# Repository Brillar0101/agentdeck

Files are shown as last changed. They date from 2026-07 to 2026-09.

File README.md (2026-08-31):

<div align="center">

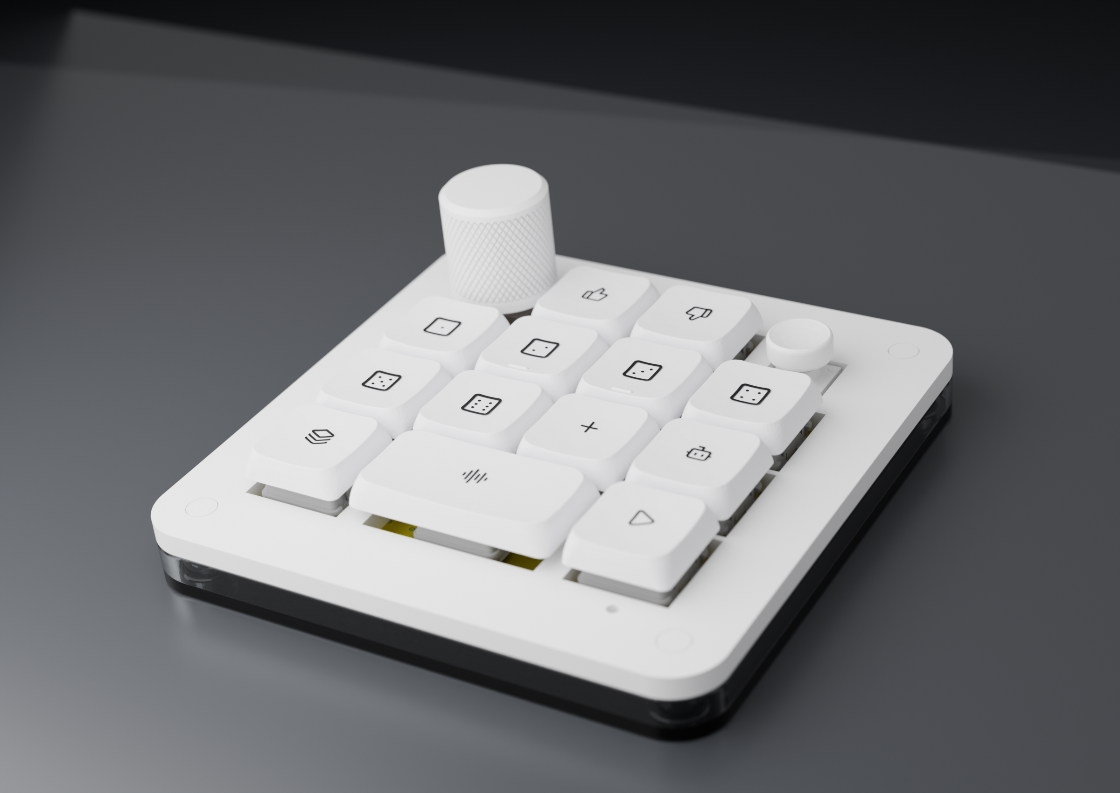
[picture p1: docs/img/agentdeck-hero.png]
AgentDeck v1


# AgentDeck

**AgentDeck is an open-source desk macropad for supervising AI coding agents.**

</div>

_AgentDeck is optimized for people running several coding agents at once who
want glanceable status and one-hand control. It is a desk device, not a
portable one: USB-C only, no battery, no radio._

- [Design notes](v1/DESIGN.md)
- [Changelog](CHANGELOG.md)
- [Licensing](LICENSING.md)

Six agent keys light up with each agent's live state (idle, thinking, working,
blocked, done). Press one to focus that session. The command keys accept or
reject work, the dial scrubs and confirms, and the joystick navigates. A host
bridge maps Claude Code hooks to the key colours, so the board answers "which
of my sessions needs me?" without alt-tabbing.

> **This is a Codex Micro-inspired project.** The concept follows OpenAI and
> Work Louder's Codex Micro, and the control layout deliberately echoes it. It
> is an independent build, not affiliated with, endorsed by, or produced with
> OpenAI, Work Louder, or Anthropic. The board, firmware and enclosure are
> original work; no Codex Micro files were used. Some material in this
> repository (vendor footprints, datasheets, reference photographs, third-party
> cap and knob models) is not ours to license. See [LICENSING.md](LICENSING.md).

## Renders

| | |
|---|---|
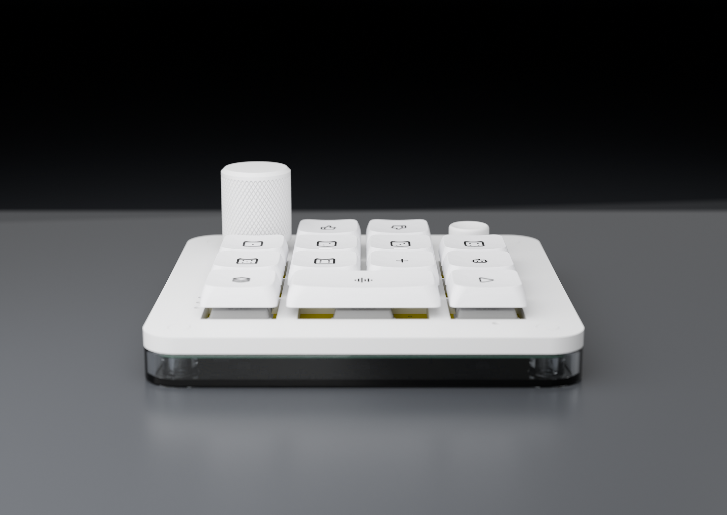
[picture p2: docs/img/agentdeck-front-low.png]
front
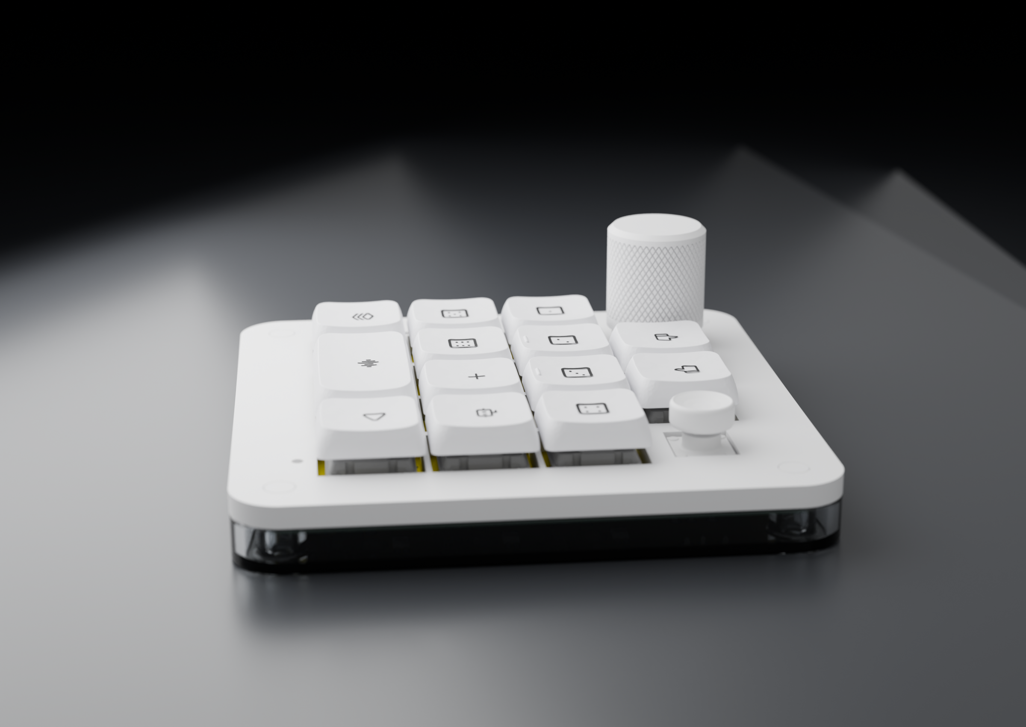
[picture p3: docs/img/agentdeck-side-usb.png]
side
|  |  |
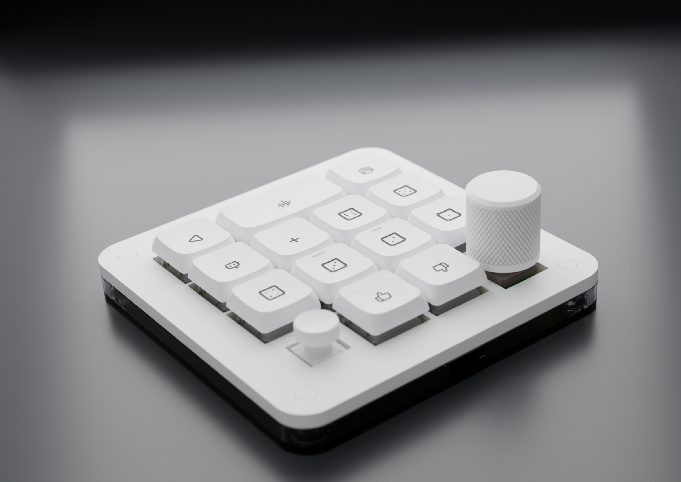
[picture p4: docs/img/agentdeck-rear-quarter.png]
rear
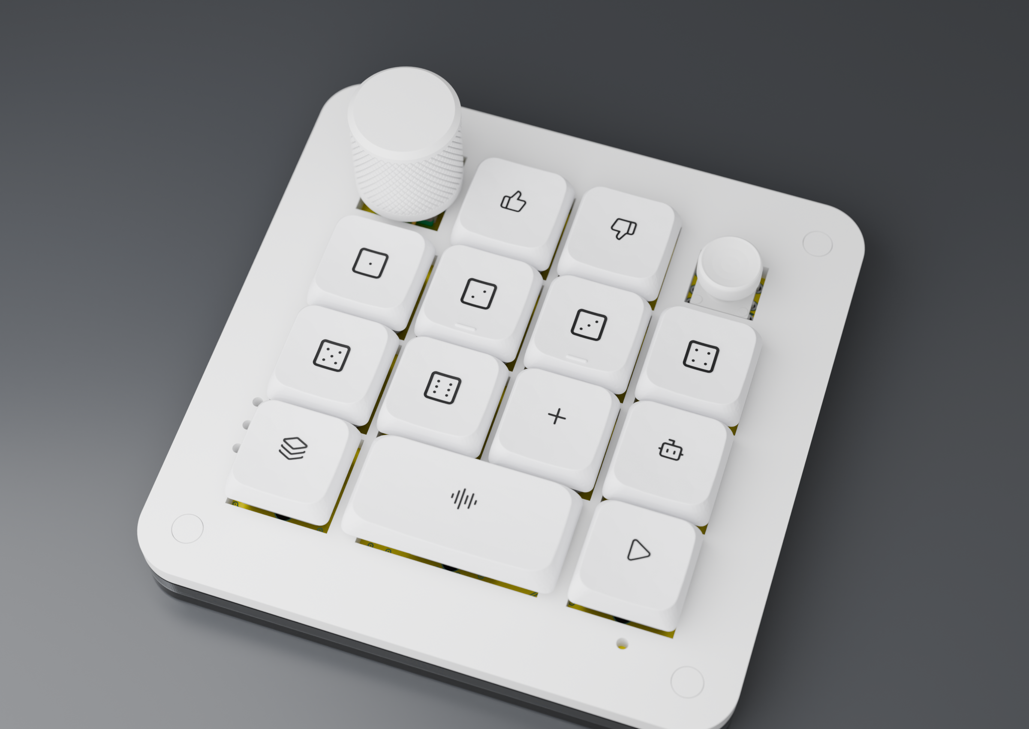
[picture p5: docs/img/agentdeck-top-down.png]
top
|  |  |

## Changelog

Hardware revisions are tracked in the [changelog](CHANGELOG.md). Because the
board is text-based KiCad, every fabricated revision maps to a tagged commit,
and a physical board can be traced back to the exact design it was made from.

## Versions

| Version | What it is | Where |
|---|---|---|
| **V1** (this release) | 95 x 95 mm 4-layer RP2040 board, 13 keys, JLCPCB PCBA | `v1/hardware/` |

What comes next (v1.0 bring-up, the v1.1 depth release, and what is
deliberately parked) is in the [roadmap](docs/ROADMAP.md).

## Status

| Part | State |
|---|---|
| Schematic + PCB | Complete. 4 layers, fully routed, 0 DRC errors, 0 ERC errors |
| Firmware | Written (CircuitPython, plus an Arduino/C++ port), untested on hardware |
| Host bridge | Written. Maps Claude Code hooks to agent-key colours |
| Enclosure | Modelled and fit-checked in Blender, STLs exported, not yet printed |
| Fab package | Gerbers, BOM and CPL generated for JLCPCB |

Nothing has been manufactured yet, so none of it is hardware-verified.

## Packages

The repository is organized by discipline. Each directory is self-contained
and has its own README where the workflow needs explaining.

| Directory | Contents |
|---|---|
| `v1/hardware/` | KiCad 10 project: `AgentDeck.kicad_pcb`, `AgentDeck.kicad_sch`, footprint / symbol / 3D libraries |
| `v1/enclosure/` | Blender assembly (`AgentDeck-v2-assembled.blend`), the parametric case generator (`src/generate_case.py`), printable STLs, keycap icon art |
| `v1/firmware/` | CircuitPython firmware (`boot.py`, `code.py`) and the Arduino port |
| `v1/host/` | `agentdeck_bridge.py`, the Claude Code hook bridge |
| `v1/fab/` | Gerbers, drill files, BOM and CPL for JLCPCB |
| `docs/` | design notes, datasheets, reference material, renders in `docs/img/` |
| `LICENSES/` | full licence texts |

## Hardware

The board is a 95 x 95 mm 4-layer PCB, drawn in KiCad 10.

- 13 Kailh Choc hot-swap keys on an 18.7 x 19.3 mm grid, each with a
  reverse-mount SK6812MINI-E RGB LED shining up through the cap
- EC11 rotary encoder (top left) and Alps SKQUCAA010 5-way joystick (top right)
- RP2040 with W25Q128 16 MB flash, USB-C, BOOT button, SWD pads
- Everything is wired directly to GPIO. There is no key matrix, so there is
  no ghosting to debounce around
- All SMD parts sit on the back of the board and hang down into the case
  tray; only the switches, encoder and joystick face up

Keycaps carry simple engraved-style icons (dice for the six agent keys,
thumbs up and down for accept and reject) rendered from
[Lucide](https://lucide.dev) glyphs. The encoder and joystick caps are white.

## Enclosure

Two printed parts plus four printed cover caps. The PCB drops into the bottom
tray component-side down, the lid closes over it, and four screws clamp the
stack into brass inserts.

| Feature | Spec |
|---|---|
| Screws | M2.5 x 8 mm button head (ISO 7380), head 4.7 x 1.3 mm |
| Lid | 5.2 mm counterbore, 2.5 mm deep, over a 2.9 mm shaft hole |
| Inserts | M2.5 brass heat-set, 4.0 mm OD x 5.0 mm, melted into a 3.6 mm boss bore |
| Cover caps | printed 5.0 x 1.2 mm plugs that hide the screw heads |
| Fit | 0.4 mm pocket clearance around the board (a deliberately loose fit) |
| USB | side port through the tray wall, sized for the plug plus a slim overmould |
| Walls | 2.6 mm, with a 0.6 mm bevel on exposed edges |

Print `v1/enclosure/case-bottom.stl`, `v1/enclosure/case-top-lid.stl`, and four of
`v1/enclosure/case-cover-plug.stl`. The case is generated, not sculpted: edit the
parameters in `v1/enclosure/src/generate_case.py` and re-run it to get new STLs.

## Firmware

Copy `v1/firmware/boot.py` and `code.py` onto a CIRCUITPY drive running
CircuitPython 9.x, with `adafruit_hid` and `neopixel` in `lib/`. An Arduino
port with identical behaviour lives in `v1/firmware/arduino/` if you prefer a
compiled build.

The command keys send Ctrl+Alt chords, the dial sets reasoning effort, and the
joystick navigates. `v1/firmware/README.md` has the full control table, colour
legend, pin map, and the three constants to confirm on first hardware.

## Development

- **Board edits**: open `v1/hardware/AgentDeck.kicad_pcb` in KiCad 10. After
  copper changes, refill zones before running DRC, then regenerate `v1/fab/`
  with `kicad-cli`.
- **Case edits**: run `v1/enclosure/src/generate_case.py` in Blender to rebuild
  the STLs from parameters.
- **Renders**: the assembly lives in `v1/enclosure/AgentDeck-v2-assembled.blend`;
  reference renders are committed under `docs/img/`.
- Derived files (board 3D exports, `.dsn`/`.ses` routing intermediates,
  autorouter logs) are gitignored and regenerate from the board.

## Licence

Multi-licensed, as is normal for open hardware. See [LICENSING.md](LICENSING.md).

| What | Licence |
|---|---|
| Software (`v1/firmware/`, `v1/host/`) | [MIT](LICENSES/MIT.txt) |
| Hardware (board, enclosure, fab files) | [CERN-OHL-S v2](LICENSES/CERN-OHL-S-v2.txt) |
| Documentation | [CC-BY-4.0](LICENSES/CC-BY-4.0.txt) |

Vendor footprints, datasheets and reference images keep their original terms.
Keycap icons are from [Lucide](https://lucide.dev) (ISC).

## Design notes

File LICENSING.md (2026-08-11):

# Licensing

AgentDeck is an open-hardware project, so different parts carry different
licences. This is the usual split for open hardware — one licence cannot sensibly
cover source code, a PCB design, and written documentation at once.

| What | Covers | Licence |
|---|---|---|
| **Software** | `firmware/`, `host/`, `*.py` | [MIT](LICENSES/MIT.txt) |
| **Hardware** | `*.kicad_pcb`, `*.kicad_sch`, `*.kicad_sym`, `*.pretty/`, `fab/`, `enclosure/*.stl`, `enclosure/*.blend`, enclosure models | [CERN-OHL-S v2](LICENSES/CERN-OHL-S-v2.txt) |
| **Documentation** | `README.md`, `DESIGN.md`, `PLAN.md`, `*/README.md`, images | [CC-BY-4.0](LICENSES/CC-BY-4.0.txt) |

SPDX identifiers: `MIT`, `CERN-OHL-S-2.0`, `CC-BY-4.0`.

The root `LICENSE` file is the MIT text so GitHub reports a licence; it applies
to the software only. Hardware and documentation are governed by the table above.

## What each one means

**MIT** (software) — do anything, including commercially and in closed products;
just keep the copyright notice. No warranty.

**CERN-OHL-S v2** (hardware) — *strongly reciprocal*. You may study, modify,
manufacture and sell the board and enclosure, but if you distribute a modified
design, or a product made from it, you must release your design sources under
CERN-OHL-S as well. This keeps derivatives open.

**CC-BY-4.0** (documentation) — reuse and adapt the writing and figures, with
attribution.

### If you would rather not have the share-alike condition

Swap the hardware licence to [CERN-OHL-P v2](https://ohwr.org/project/cernohl)
(permissive — no obligation to publish your modifications). That is a one-file
change plus an edit to the table above. CERN-OHL-S was chosen as the default
because it keeps improvements to the board flowing back to the community.

## Third-party material

Some content in this repository is **not** covered by the licences above and
remains under its original terms:

- `JLC.3dshapes/`, `JLC.pretty/` — component footprints and 3D models from LCSC /
  JLCPCB and their manufacturers
- `docs/datasheets/`, `docs/reference/*.pdf` — vendor documentation (Raspberry Pi,
  Alps and others), redistributed for reference only
- `docs/reference/*.webp`, `docs/reference/*.png` — **product photographs of
  OpenAI / Work Louder's Codex Micro.** These are not ours, are used only as
  design reference, and are **not** licensed for redistribution. Remove them
  before making this repository public.
- `docs/reference/pi-codex-micro/` — a clone of a third-party project
  (github.com/jal-co/pi-codex-micro) under its own licence; excluded from git
- `enclosure/keycaps/`, `enclosure/encoder/` — keycap and knob models sourced from their
  respective authors; check the original terms before redistributing

## Inspiration and independence

AgentDeck is an **independent, Codex Micro-inspired project**. The idea of a
macropad for supervising coding agents — agent keys that show live state, an
accept/reject pair, a reasoning-effort dial — follows OpenAI and Work Louder's
**Codex Micro**, and the layout here deliberately echoes it.

This project is **not affiliated with, endorsed by, or produced in cooperation
with OpenAI, Work Louder, or Anthropic.** The schematic, PCB layout, firmware and
enclosure in this repository are original work; no files from the Codex Micro were
used. "Codex", "Codex Micro", "OpenAI", "Work Louder", "Claude" and "Anthropic"
are trademarks of their respective owners, referenced here only descriptively.
The "AgentDeck" name is a working project name, not a product name, and carries
no claim to Anthropic's marks.

## Attribution

Copyright (c) 2026 Brillar0101 — for the original work only. Third-party material
listed above stays with its owners.

There is no warranty. Nothing in this repository has been manufactured or
hardware-verified — see the status table in the README.

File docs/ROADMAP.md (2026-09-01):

# Roadmap

One version at a time. A milestone is not started until the previous one is
finished, and "finished" is defined at the top of each section.

## v1.0 - manufacture and validate (current)

Nothing in this repo has ever run on real hardware. v1.0 is the fab order,
assembly, and bring-up of the V1 board as designed.

Finished when: an assembled board enumerates over USB, the CircuitPython
firmware runs, all 13 keys / encoder / joystick / LEDs work, the Claude Code
hook bridge drives agent-key colours on a real desk for a full workday.

- Order PCBs + parts from the existing `v1/fab/` package (JLCPCB PCBA)
- Assemble, print the enclosure, flash, bring up
- Fix whatever the hardware disagrees with (expect firmware patches; record
  them in the changelog)
- Live with it for a week; collect the annoyance list

## v1.1 - depth release (no copper changes)

Everything here runs on the v1 board as manufactured. Software and firmware
only, so it can be developed in parallel while v1.0 boards are in transit.

The design brief is the Codex Micro backlash inverted: bidirectional control,
a microphone story, Linux support, and integration deep enough that no $50
macro pad could replicate it.

### Bridge (host side)
- Bidirectional control: blocked agent pulses its key; dedicated approve /
  deny keys answer permission prompts from the deck
- Interrupt key: short-press stops the selected agent, long-press stops all
- Focus-on-press: tmux-first (`switch-client` / `select-window` - works on
  X11, Wayland, and over SSH), window-manager raise as fallback only
- Dispatch keys: saved prompts / slash commands bound per-project profile
- Role packs: Dispatch mode loads a curated layout from a YAML pack file
  (key -> label -> colour -> skill/command). Ships with a Software Engineer
  pack bound to real slash commands (review, tdd, verify, build-fix,
  security-scan, simplify, plan, continue, commit). Packs point at skills
  and slash commands, never long inline prompt strings - skills version and
  improve independently; frozen prompts rot. More packs are just more files
- Pipelines: a pack key can run an ordered sequence of steps (each a
  skill/command pointer plus a pass condition) instead of one action. The
  key row is the progress bar - stages light green as they pass; a failing
  stage goes red, halts the pipeline, and pressing it focuses the failure.
  Examples: PCB release (ERC -> DRC -> gerbers -> BOM stock -> CPL -> tag),
  SWE ship (test -> review -> security -> commit -> push). Pipelines are
  always interruptible - the interrupt key aborts a running pipeline
- Push-to-talk: hold key, speak, release; local transcription to the active
  session (host microphone)
- Meeting capture: record key toggles; solid red while recording (visible to
  everyone at the desk); local Whisper transcription; Claude-structured
  Markdown notes (summary / decisions / action items) to a configured folder
- Token awareness without a screen: a configured key shifts green -> amber ->
  red as the rate-limit window burns; rate-limited state gets its own colour
- Modes (layered layouts, Stream Deck-style): named layouts - Agents /
  Dispatch / Desk - switched by encoder press and auto-switched by context
  (recording flips to Desk). Hard cap of 3 modes. Each mode has its own
  colour theme so the active mode reads at a glance; a host-side HUD overlay
  flashes the current layout for 2 s on mode change (keys have no displays -
  per-key e-paper labels stay parked and are the eventual fix). The
  interrupt key is mode-invariant: it means stop in every mode, always

### Platform
- Linux and macOS both first-class
- Ship `99-agentdeck.rules` udev rule for raw-HID access on Linux
- Bridge stays local-only: no cloud calls, no telemetry

### Companion (the deck as a two-sided device)
- Agent-side API: a local bridge endpoint sessions can call deliberately -
  `signal(urgency)` (steady / slow pulse / urgent flash - "FYI" vs "need a
  decision" vs "about to do something hard to reverse"), `ask(options)`
  (pose a question that lights two keys; the pressed key is the answer),
  `presence()` (recording / away / active, so an agent batches questions
  instead of blocking while the human is in a meeting)
- Do-not-disturb key: mutes host notifications and flips presence to "away"
  so agents hold non-urgent questions until it is released
- End-of-day key: one press asks Claude for a digest of what every session
  did today - shipped, blocked, awaiting review - as a Markdown note

### Quality bars
- Agent state change to key colour change <= 1 s
- 8 h session without state drift or reconnect
- Bridge crash never disturbs the sessions it watches; deck unplug degrades
  to plain macro-pad mode

Finished when: one full workday supervising 4+ real Claude Code sessions with
at least one permission approved and one runaway agent interrupted from the
deck, without alt-tabbing to check status.

## V2 - wireless platform

Decision (2026-08-30): AgentDeck goes wireless. V2 is a 20-key (4x5)
control surface on the power/radio platform recovered from the deleted V3
design (git history, pre-297fabb): ESP32-S3-WROOM, LiPo + charging,
USB-C + BLE.

Key layout (decided 2026-08-30, cut 2026-09-01): 4x5 diode matrix. Row 0
is the fixed system row - INT / PTT / REC / MODE / DND - never remapped;
rows 1-3 are 15 assignable keys (8 agent keys + 7 action keys). An action
row doubles as the pipeline progress bar. The board stays at V3's 150 x
110 mm: the column freed by going 6 -> 5 becomes the right-hand strip that
holds the 103450 battery pocket and the joystick. V1 stays 13 keys as
designed; it is the testbed, not the product surface.

Architecture:
- ESP32-S3-WROOM module (BLE + USB in one chip; module carries modular
  FCC/CE radio certification, which a commercial version inherits)
- Dual-mode: BLE HID + custom GATT for the state protocol; USB-C is
  charger and full wired fallback - plugged in, the cable wins
- Protected 103450-class LiPo (~2000 mAh). Charger stays TP4056 + AO3401A
  load-share FET (run-while-charging, battery isolated when USB present)
  and battery level stays the ADC divider: the BQ24074 / fuel-gauge parts
  are QFN/DFN and break the hand-solder floor. Swap in if V2 ever moves to
  JLCPCB assembly. Charge LED and ship mode carried from the V3 design
- 2-layer board (decided 2026-09-01): the scripted router closes all but a
  few links; those are hand-routed in KiCad
- Firmware: the Arduino/C++ port becomes primary (CircuitPython BLE on
  ESP32-S3 is not dependable)
- Bridge grows a BLE transport (bleak) beside HID; every reconnect repaints
  full state so a BLE drop can never leave stale colours
- The 0.96" OLED carried by the V3 design is in (token screen lands early)
- V3's capacitive touch pad is out: PTT is a mechanical key in the system
  row. The Alps 5-way joystick from V1 is in, on GPIO15/16/17/18/1

Phases:
- A (wk 1): recover V3 assets to a `v2-wireless` branch, re-verify LCSC
  stock, write the delta spec - DONE 2026-09-01 (see v2/DESIGN.md)
- B (wk 2-4): schematic + layout; RF keepout, battery bay in enclosure -
  schematic generated ERC-clean and PCB placed/autorouted 2026-09-01 via
  v2/tools; remaining: review, enclosure regeneration, LCSC stock pass
- C (wk 4-6): fab + PCBA; firmware port and BLE transport built while
  boards are in transit
- D (wk 6-9): bring-up; measure 8 h battery target and <= 1 s BLE state
  latency; land the v1.1 feature set on this board

Hedge, in parallel, zero schedule cost: fab the finished V1 wired board
(~$60) as the testbed - keys, LEDs, enclosure fit, and the entire bridge
stack validated on real hardware while V2 is still in layout.

Risks: BLE pairing UX; battery heat in an enclosed printed case (protected
cell, vented design, cell away from the LED field); power-path bugs (bench
test the charger standalone); firmware port slower than hoped (wired HID
fallback stays alive from day one).

## Parked (not before V2 ships)

Deliberately not scheduled. Reopening any of these early is a scope change,
not a roadmap step.

- Colour LCD status strip (rate-limit runway, per-session context fill, burn
  rate, session cost) - unless the V2 OLED stretch covers it
- Per-key e-paper labels (e-ink shows the label, RGB shows the state)
- Onboard far-field microphone
- CNC aluminium enclosure
- Cross-agent adapters / plugin SDK

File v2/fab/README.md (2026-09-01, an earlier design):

# V2 fabrication package (JLCPCB)

Sourcing was re-checked against the JLCPCB assembly library on 2026-09-01
(every LCSC code in `../PARTS.yaml`, stock and basic/extended status).

| File | What |
|---|---|
| `jlcpcb-bom.csv` | JLCPCB BOM (Comment, Designator, Footprint, LCSC Part #) - 27 lines, 119 placements |
| `jlcpcb-cpl.csv` | JLCPCB pick-and-place, filtered to BOM designators |
| `consigned-parts.csv` | parts JLCPCB does not stock: prog pads (no part), battery |
| `kicad-pos.csv` | raw KiCad position export the CPL was made from |

Regenerate the CPL after routing changes nothing - positions are fixed - but
regenerate both files if the schematic changes:

    kicad-cli pcb export pos --format csv --units mm --side both --exclude-dnp \
        -o v2/fab/kicad-pos.csv v2/hardware/AgentDeckV2.kicad_pcb
    python3 ~/.claude/skills/bom/scripts/translate_bom_pnp.py pnp \
        v2/fab/kicad-pos.csv -o v2/fab/jlcpcb-cpl.csv --bom v2/fab/jlcpcb-bom.csv

The schematic symbols carry an `LCSC` field, so KiCad's own BOM export
(Reference/Value/Footprint/LCSC -> Designator/Comment/Footprint/LCSC Part #)
reproduces `jlcpcb-bom.csv`.

## Library status (2026-09-01)

- Basic (no feeder fee): 1N4148W, AO3401A, SS34, tact switches, every
  resistor and capacitor.
- Extended ($3 each): ESP32-S3-WROOM-1-N8R2, SK6812MINI-E, SN74AHCT1G125,
  EC11 encoder, USB-C, USBLC6-2SC6, TP4056, RT9080-33GJ5, JST-PH, MSK12C02,
  SKRHABE010 joystick - 11 parts, ~$33 of feeder fees per order.
- Swapped for stock: LDO ME6211C33 (17 in stock) -> RT9080-33GJ5 C841192
  (same SOT-23-5 pinout, 600 mA, 2 uA Iq). Joystick SKQUCAA010 (THT, not
  stocked) -> SKRHABE010 C139794 (SMD, 4.7k in stock).
- Kailh Choc CPG135001D01/02/03 (C400229/230/231) ARE in the library but at
  zero stock - consigned until they restock; hand-soldered anyway (THT).
- The 0.96" OLED is the JLCPCB library module C5248080 (HS96L03W2C03, 4-pin
  THT header) with JLC's own footprint and STEP model.

## 3D models

`../hardware/jlc3d/JLC.3dshapes/*.step` were pulled from JLCPCB/EasyEDA per
LCSC code (`easyeda2kicad --3d --lcsc_id=Cxxxxx`). V2.pretty footprints
reference them; for the other footprints run, with KiCad closed:

    <KiCad python> v2/tools/attach_3d.py

then check the 3D viewer - EasyEDA models occasionally need a 90/180 turn.

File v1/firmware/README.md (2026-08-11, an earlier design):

# AgentDeck Firmware

CircuitPython firmware turning the board into an agent-control surface, plus a
host bridge that drives the agent keys from real agent activity.

An Arduino/C++ port with identical behaviour lives in
[`arduino/`](arduino/README.md) if you prefer a compiled build over
CircuitPython.

## Install

1. Hold **BOOT**, plug in USB-C → the `RPI-RP2` drive appears.
2. Copy the [CircuitPython 9.x UF2 for Raspberry Pi Pico](https://circuitpython.org/board/raspberry_pi_pico/)
   onto it (the generic Pico build is correct — all pins used are GP0–GP24).
3. From the [Adafruit CircuitPython bundle](https://circuitpython.org/libraries),
   copy into `CIRCUITPY/lib/`: `adafruit_hid/` and `neopixel.mpy`.
4. Copy `boot.py` and `code.py` to the `CIRCUITPY` root, then replug.

## What each control does

```
    [ DIAL ]   ACCEPT   REJECT    [ JOYSTICK ]
    AGENT1     AGENT2   AGENT3    AGENT4
    AGENT5     AGENT6   NEWCHAT   MODEL
    FN        [ PUSH-TO-TALK ]    MACRO
```

| Control | Action | Sends |
|---|---|---|
| **Agent 1–6** | select that agent; the key colour *is* its live state | `Ctrl+Alt+1`…`6` |
| **Accept** | approve the agent's changes | `Ctrl+Alt+Enter` |
| **Reject** | interrupt / decline | `Ctrl+Alt+Backspace` |
| **New chat** | start a fresh session | `Ctrl+Alt+N` |
| **Model** | cycle model | `Ctrl+Alt+M` |
| **Push-to-talk** | wide key, **held** while dictating | `Ctrl+Alt+Space` (held) |
| **Macro** | free slot | `Ctrl+Alt+X` |
| **FN** | hold for a second layer (adds Shift to any chord) | — |
| **Dial** | reasoning effort up / down | `Ctrl+Alt+=` / `Ctrl+Alt+-` |
| **Dial press** | cycle thinking mode | `Ctrl+Alt+T` |
| **Joystick** | navigate | `Ctrl+Alt+I/K/J/L`, centre `Ctrl+Alt+O` |

Ctrl+Alt chords were chosen so nothing collides with normal typing. Rebind by
editing `BINDINGS`, `DIAL_*` and `JOY_BIND` at the top of `code.py`.

## Agent-state colours

| State | Colour |
|---|---|
| `idle` | dim violet |
| `think` | amber, pulsing |
| `work` | orange |
| `block` | **red, blinking** — wants your attention |
| `done` | green |
| `err` | magenta |

Only the six agent keys show state; the other keys carry a steady hint colour
and brighten while FN is held. The FN key (SW14) has its own LED: dim white at
rest, bright white while the layer is active.

## Host bridge

```bash
pip install pyserial
python3 ../host/agentdeck_bridge.py demo             # cycle every state
python3 ../host/agentdeck_bridge.py agent 3 block    # agent 3 red/blinking
python3 ../host/agentdeck_bridge.py all done         # all six green
python3 ../host/agentdeck_bridge.py watch            # print key/dial/joystick events
```

Wire it to Claude Code with hooks — a ready-to-paste `settings.json` snippet is
in the header of `host/agentdeck_bridge.py` (UserPromptSubmit → thinking,
PreToolUse → working, Notification → blocked, Stop → done).

## Hardware map

| Function | GPIO |
|---|---|
| SW1–SW12 | GP0–GP11 |
| SW14 (FN, bottom-left) | GP20 |
| Dial A / B / press | GP12 / GP13 / GP14 |
| Joystick U/D/L/R / centre | GP15–GP18 / GP19 |
| SK6812 chain (13 LEDs) | GP21 |
| Aux LEDs link / activity / error | GP22 / GP23 / GP24 |

## Verify on first hardware

Three things can only be confirmed with a real board — each is a one-line change:

- **Joystick direction order** — `JOY_NAMES = "UDLRC"`; reorder if up/down/left/right feel wrong.
- **LED chain order** — indices assume the chain runs SW1→SW12; check with `all done`.
- **Aux LED polarity** — they're driven active-high.

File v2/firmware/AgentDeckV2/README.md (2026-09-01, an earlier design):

# AgentDeck V2 firmware

Arduino (ESP32-S3), dual-transport HID: USB when plugged, BLE ("AgentDeckV2")
when on battery. Host protocol is V1's CDC protocol plus `S <line> <text>` for
the OLED. See `docs/DESIGN-V2.md` for architecture; `pins.h` mirrors the
generator's PINOUT table (diff them after any hardware change).

## Build

```
arduino-cli compile --fqbn "esp32:esp32:esp32s3:USBMode=default,CDCOnBoot=cdc,FlashSize=8M,PSRAM=enabled" v2/firmware/AgentDeckV2
arduino-cli upload  --fqbn "esp32:esp32:esp32s3:USBMode=default,CDCOnBoot=cdc,FlashSize=8M,PSRAM=enabled" -p /dev/tty.usbmodem* v2/firmware/AgentDeckV2
```
Libraries: Adafruit NeoPixel, U8g2, NimBLE-Arduino.

First flash of a blank board: hold BOOT, tap RESET, release BOOT, then upload
(native USB). After the first flash, auto-reset works.

## Verify on first hardware (V1 tradition)

- [ ] Matrix orientation: ROW/COL vs physical grid (press K1, check index 0)
- [ ] Diode direction = COL2ROW assumed by scan (rows driven low)
- [ ] LED chain order vs key numbering; GRB color order
- [ ] Touch threshold: log `touchRead(PIN_TOUCH)` idle vs pressed, set margin
- [ ] VBAT ADC calibration against multimeter at full/half charge
- [ ] CHRG/STDBY polarity from TP4056 while charging
- [ ] BLE pairing from macOS; auto-switch on USB unplug
- [ ] OLED address (0x3C vs 0x3D)

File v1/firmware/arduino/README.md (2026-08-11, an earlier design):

# AgentDeck firmware, Arduino version

An Arduino/C++ port of the CircuitPython firmware in `../code.py`. It is a
feature-for-feature match: all 13 keys, the encoder, the joystick, the per-key
LED state colours, the FN layer, and the same host serial protocol.

Use whichever you prefer. CircuitPython is quicker to edit on-device (drag a file
onto the CIRCUITPY drive); the Arduino build compiles to a single UF2 and has no
filesystem to manage.

## Build

- **Core:** arduino-pico by Earle Philhower
  (`https://github.com/earlephilhower/arduino-pico`). Add its board manager URL,
  then install "Raspberry Pi Pico/RP2040".
- **Board:** pick your RP2040 board.
- **Tools -> USB Stack:** set to **Adafruit TinyUSB**. This is required so the
  device can be a USB HID keyboard and a serial port at the same time.
- **Library:** install **Adafruit NeoPixel** (Library Manager). The `Keyboard`
  and `Adafruit_TinyUSB` libraries ship with the core.

Open `AgentDeck/AgentDeck.ino`, select the port, and upload. To enter the
bootloader on a fresh board, hold BOOT while plugging in USB.

## One difference from the CircuitPython build

The CircuitPython firmware exposes two USB serial channels (a REPL console plus a
separate data channel). The Arduino build exposes a **single** serial port and
sends the host protocol over it, because there is no REPL to keep clear.

The host bridge (`../../host/agentdeck_bridge.py`) finds the pad by looking for
"AgentDeck" in the USB descriptor, which this sketch sets, so the same bridge
works with either firmware without changes.

## Pin map and protocol

Identical to the CircuitPython version. See the header comment in
`AgentDeck/AgentDeck.ino` and the tables in `../README.md`.

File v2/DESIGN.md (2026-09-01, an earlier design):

# AgentDeck V2: Wireless AI Control Deck (20 keys, ESP32-S3, BLE + USB-C)

> Method: script-generated KiCad (v2/tools, tracked in git), freerouting, home hand
> assembly with parts ordered from JLCPCB/LCSC. V2 is the wireless platform decided in
> docs/ROADMAP.md: V1's control-surface identity on the ESP32-S3 / LiPo platform that
> was designed (never built) as "V3" before the 2026-08-30 reset - see git history.

## Version naming (authoritative)

| Version | What it is | Where |
|---|---|---|
| V1 | 95x95 4-layer RP2040 board, 13 keys, USB only. The wired testbed | `v1/` |
| V2 | THIS: 20 keys (4x5), ESP32-S3, OLED, joystick, 2000 mAh LiPo, USB-C + BLE | `v2/` |

The pre-reset V2 (PowerDeck two-deck concept) and V3/V4 paper designs were deleted at
commit 297fabb; this V2 recovers the V3 platform work.

## Feature set (docs/ROADMAP.md, V2 section)

20-key 4x5 Choc matrix (row 0 = fixed system row: INT / PTT / REC / MODE / DND;
rows 1-3 assignable: 8 agent keys + 7 action keys) · per-key SK6812 · 0.96" OLED
(mode / agent state / battery / rate-limit runway) · EC11 encoder · Alps 5-way
joystick (carried from V1) · USB-C + BLE HID, cable wins when plugged · protected
2000 mAh 103450 LiPo, TP4056 charge + AO3401A load share (run-while-charging) ·
power switch · same host protocol as V1 (`v1/host/agentdeck_bridge.py`) + screen cmd.

Deviations from the roadmap's first sketch, decided during generation: the charger
stays TP4056 + load-share FET rather than a BQ24074-class power-path IC, and battery
level stays an ADC divider rather than a fuel-gauge IC - both alternatives are
QFN/DFN parts that break the hand-solder floor (0.5 mm pitch, no exposed-pad-only
packages). Swap them in if the board ever moves to JLCPCB assembly. The V3 touch pad
is gone: PTT is a mechanical key in the system row.

## Architecture

```
USB-C (J1) ─ USBLC6 ESD ─ D+/D- ──────────────► ESP32-S3-WROOM-1 (U1)
   │ VBUS 5V                                      │ GPIO matrix 4 rows × 5 cols (20 keys
   ├──► TP4056 (U4) ──► BAT+ ──► JST-PH (J2) ─ LiPo│   + 20× 1N4148W)
   │        │ PROG 2.4k = 500 mA                  │ I2C → OLED (OLED1)
   │        └ CHRG/STDBY → status nets            │ GPIO15/16/17/18/1 ← SKQUCAA010 joystick
   ├──► Q1 AO3401A gate (load share: USB present  │ GPIO → EC11 A/B/SW
   │      disconnects battery from VSYS)          │ GPIO → LED_DATA → U2 AHCT125 → chain
   ▼                                              │ ADC → VBAT ÷ (100k/47k)
  VSYS (5V USB or 3.7–4.2V battery, diode-OR) ────┤ EN/IO0 ← BOOT/RESET tacts + prog pads
   ├──► SK6812 ×20 power rail (3.7–5.5V OK)       │
   └──► ME6211C33 (U5) ──► +3V3 ──► U1, OLED, pulls
        (low-Iq LDO; power switch SW25 in VSYS path)
```

Key GPIO budget (S3): 4+5 matrix, 2 I2C, 5 joystick, 3 encoder, 1 LED data, 1 ADC,
2 status (CHRG/STDBY sense), spare 2 (GPIO38/39). Strapping pins (GPIO0/3/45/46) kept free of
matrix duty per datasheet §strapping.

## Component placement rules (datasheet-driven)

Datasheets live in `docs/datasheets/` (V1 set) and `docs/datasheets/v2/`:
`esp32-s3-wroom-1_datasheet.pdf`, `esp32-s3-hw-design-guidelines.pdf`, `tp4056.pdf`,
plus V1's `sk6812mini-e.pdf`. ME6211 + AO3401A sheets: fetch at order
time (LCSC links rotated). `v2/tools/place_pcb.py` implements these as constraints:

1. **ESP32-S3-WROOM antenna** (HW design guidelines §PCB layout): antenna end
   overhangs the board edge, or sits on an edge with **≥15 mm copper keepout** on all
   layers under/around the antenna; no traces, no pour, no silk. Module GND pad
   stitched with vias to bottom pour.
2. **Decoupling** (guidelines §power): 100 nF within **2 mm** of each module 3V3 pin;
   10 µF bulk within 10 mm; LDO in/out caps at the LDO pads (ME6211 needs ≥1 µF
   ceramic on out, X5R/X7R).
3. **USB differential pair** (V1 lore + guidelines): D+/D− routed as a coupled pair,
   length-matched ±0.5 mm, over solid ground, no layer change between connector, ESD
   part, and module; ESD diode (U3) placed at the connector, stubs minimized. On a
   2-layer 1.6 mm board true 90 Ω is not achievable, keep the pair **short (<15 mm)**
   which is fine at full-speed USB (V1 shipped the same compromise, documented).
4. **TP4056 thermal** (tp4056.pdf): it is a linear charger and dissipates
   (VBUS−VBAT)·Icharge ≈ 0.6 W worst case at 500 mA. Copper pour on its tab/GND pins
   ≥1 cm², thermal vias to bottom pour; keep ≥5 mm from the battery pocket.
5. **SK6812 chain** (sk6812mini-e.pdf): 100 nF per LED at its VDD; power injected at
   both chain ends (20 LEDs ≈ 1.2 A worst-case white, VSYS pour, not a trace);
   data line series 330 R at the head; keep data stubs < 5 mm.
6. **Joystick** (Alps SKQUCAA010, THT snap-in): right-hand strip below the battery
   pocket, clear of the key field; directions are plain GPIO inputs with internal
   pullups, COM to GND - no special copper rules.
7. **Matrix diodes**: cathode to row (COL2ROW), consistent orientation for firmware;
   diode next to its switch pad, not bussed at a distance.
8. **Load-share FET** (NeuralCard DESIGN.md §3): Q1 gate to VBUS with 100 k bleed,
   source to VSYS, drain to BAT side, battery isolated when USB present; place at
   the power entry corner with the TP4056.
9. **EC11/tacts/power switch**: mechanical parts on board edges per their drawings;
   MSK12C02 actuator overhangs the edge (NeuralCard pattern).
10. **OLED FPC tab**: solder tab lands on top edge strip; keep the flex bend radius
    area free of components for 5 mm behind the tab.

## PCB best practices adopted (2-layer)

Decision 2026-09-01: V2 stays 2-layer. The scripted flow (freerouting +
finish_v2 repair) closes all but a handful of links at this density; those
leftovers are hand-routed in KiCad and recorded in the changelog. The USB
pair and the module decoupling comb are pre-routed and locked by place_pcb so
they survive re-runs.

- **Bottom layer = near-solid GND pour**; top pour GND in gaps; stitch vias on a
  ~10 mm grid and around every connector/IC (return-path rule: every signal has an
  adjacent ground return).
- Power distribution as pours/wide traces: VSYS pour region on top around the LED
  field; 3V3 min 0.5 mm trace ring.
- All vias ≥ 0.45/0.3 mm (standard fab bracket, pricing lesson from V1 rev0.1).
- Track/clearance defaults 0.2/0.2 mm (hand-friendly, easy fab); 0.15 only where the
  OLED tab forces it.
- Silkscreen: every ref + pin-1 marks + polarity bars; flashing instructions and
  pinout legend printed on the board (V1 style); text ≥1 mm height (JLC legibility , 
  V1 DRC lesson).
- No components under the battery pocket footprint (keepout zone in the PCB and a
  matching pocket in the case bottom). V2 pocket: 34 x 50 mm on the right-hand strip
  (x 108-142, y 12-62) for a 103450 cell; the key field ends at x ≈ 110.

## Firmware (v2/firmware, Arduino ESP32-S3)

Matrix scan/debounce → USB HID *and* BLE HID (NimBLE), auto-switch by USB presence;
OLED status UI; joystick edges → host (`J` lines); system-row roles → host (`K` lines); SK6812 state colors (V1 language: idle/think/
work/block/done/err); battery % from ADC; CDC protocol = V1's plus `S <line> <text>`.
USB name "AgentDeckV2" (agentdeck_bridge.py matches by name).

## Rules recap (see v2/PARTS.yaml header)

Manifest-first · 2D+3D dims verified by v2/tools/verify_parts.py · hand-solder floor
0.5 mm pitch · JLC/LCSC stock status per line · V1 untouched · v2 tools tracked.

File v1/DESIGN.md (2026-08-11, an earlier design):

# AgentDeck: hardware design (v0, spec freeze)

> Companion to PLAN.md (research + rationale). This file tracks the build.
> Method: fully script-generated KiCad, same pipeline as NeuralCard
> (generator scripts -> freerouting -> JLCPCB PCBA).

## Version roadmap

- **V1 (this board)**: single integrated PCB, keys + RP2040 + all I/O on one
  95x95mm board, USB-C powered. Fully routed, DRC-clean, ordered-ready.
- **V2**: two-deck system, this controller as the upper deck + a separate
  lower PowerDeck (Qi wireless charging + Li-ion battery) that attaches
  magnetically and feeds 5V through pogo pins. Spec:
  ~/kicad-projects/agentdeck-powerdeck/DESIGN.md.

## Frozen decisions (v1)

- **MCU**: RP2040 + W25Q128 QSPI flash, QMK firmware, VIA raw HID
  (usage page 0xFF60) so pi-codex-micro-style extensions port over.
- **Connectivity**: USB-C only. No battery, no BT (v2 candidate: nRF52840).
- **Controls**: 12 Kailh Choc v1 keys on hotswap sockets (6 frosted RGB
  agent keys + 4 command keys + wide-ish action key + 1 more), EC11 dial
  with push, Alps SKQUCAA010 5-way joystick, TTP223 touch pad, 3 aux 0603
  status LEDs.
- **Wiring**: no matrix. RP2040 has 30 GPIO; everything direct:
  12 keys + encoder(3) + joystick(5) + touch(1) + SK6812 data(1) +
  aux LEDs(3) = 25 GPIO. Simplest possible firmware, no ghosting, ever.
- **Footprint**: ~95 x 95 mm (grown from 90 for corner-screw clearance), Choc spacing 18 x 17 mm.
- **Recovery**: RP2040 UF2 bootloader (BOOTSEL button on back). Unbrickable.

## Verified parts (JLCPCB, checked 2026-07-20)

| Block | Part | LCSC | Notes |
|---|---|---|---|
| MCU | RP2040 | C2040 | LQFN-56 |
| Flash | W25Q128JVSIQ | C97521 | 16 MB QSPI |
| Crystal | 12 MHz 3225 | C9002 | |
| LDO | AMS1117-3.3 | C6186 | VBUS -> 3V3 |
| USB | TYPE-C-31-M-12 | C165948 | + 2x 5.1k CC pulldowns |
| ESD | USBLC6-2SC6 | C7519 | on D+/D- |
| RGB | SK6812MINI-E x6 | C5149201 | reverse-mount through plate |
| Touch | TTP223-BA6 | C80757 | PCB pad antenna |
| Socket | Kailh CPG135001S30 x12 | C5333465 | Standard PCBA + fixture |
| Encoder | ALPS EC11E1834403 | C361165 | 18 pulse, push, THT wave |
| Joystick | ALPS SKQUCAA010 | C9900002499 | custom fp+symbol from Alps datasheet |

Libraries pulled into JLC.kicad_sym / JLC.pretty / JLC.3dshapes via
easyeda2kicad (all but the joystick).

Not yet sourced: Choc switches themselves and keycaps (bought separately,
not PCBA), frosted caps for agent keys (sourcing risk flagged in PLAN.md).

## Circuit blocks (to implement in gen_schematic.py)

1. Power: USB-C VBUS -> AMS1117 -> 3V3; bulk + decoupling. SK6812 run
   from 5V VBUS rail (datasheet-legal with 3V3 data at short trace; add
   level check during validation).
2. RP2040 core: crystal + load caps, QSPI flash, decoupling per hardware
   design guide, BOOTSEL button, USB D+/D- through USBLC6, SWD test pads.
3. Inputs: 12 direct-wired sockets, EC11 (A/B/SW), 5-way (4 dir + center),
   TTP223 with its sense pad on copper.
4. LEDs: SK6812 chain of 6 under the agent keys, 3 aux 0603s near touch.

## Datasheet-required practices (sources in datasheets/, bindings for the design)

### RP2040: "Hardware design with RP2040" (Raspberry Pi, ch. 2)
- 100nF decoupling per power pin, placed close (pins 48/49 may share one).
- Internal 1.1V regulator: 1uF close to BOTH VREG_VIN and VREG_VOUT;
  VREG_VOUT feeds the DVDD pins. Small ceramics satisfy the ESR limits.
- LDO: 10uF at input and output (their NCP1117 example; ours AMS1117).
- Flash W25Q128JVS: QSPI wired directly with short tracks; QSPI_SS 10k
  pull-up footprint (DNF for this flash); 1k series resistor from QSPI_SS
  to BOOTSEL button pulling to GND (boot strap). R's close to the flash.
- Crystal: Abracon ABM8-272-T3 (guide-recommended part) sourced at JLC as
  C20625731; 2x 15pF loads + 1k series on XOUT, exactly per guide 2.3.
- USB: 27R series resistors on DP/DM close to the chip (required); 90R
  differential impedance target. Their recipe (0.8mm trace/0.15mm gap)
  assumes a 1mm board; ours is 1.6mm (joystick snap-in requires it), so
  USB FS runs short traces over solid ground and is documented as a
  known impedance compromise (standard for 1.6mm keyboard PCBs).
- RUN: pull-up to 3V3, exposed on the SWD pad row.

### SK6812MINI-E (OPSCO SPC rev 02)
- VDD range +3.7 to +5.5V: MUST be powered from VBUS 5V, not 3V3.
- VIH = 0.7*VDD (3.5V at 5V): 3.3V GPIO is OUT OF SPEC directly ->
  SN74AHCT1G125DBVR (C7484) level shifter between GPIO21 and first DIN
  (NOT the AHC variant C7468 - CMOS thresholds would not shift).
- Pinout 1 VDD / 2 DOUT / 3 GND / 4 DIN; land pattern per section 6.
- Practice: 100nF per LED at VDD/GND, series resistor (~300R) at the
  head of the data line, 800kHz unipolar RZ protocol (QMK ws2812 driver).
- MSL 5a moisture sensitivity: assembly-house handled at JLC.

### TTP223-BA6 (Tontek v2.1)
- Pinout: 1 Q / 2 VSS / 3 I(sense) / 4 AHLB / 5 VDD / 6 TOG.
- TOG and AHLB have internal 28k pull-downs; leave BOTH unconnected =
  direct mode, active-high output (what QMK wants). No straps needed.
- C1 100nF between VDD and VSS with very short tracks: required.
- Cs sensitivity cap, 0-50pF NPO, sense pad to VSS: fit a DNP 0603 so
  sensitivity is tunable; no cap = maximum sensitivity.
- Sense pad: short trace, no parallel/crossing signals, no metal overlay.
- 0.5s power-on stabilization: firmware ignores touch for first 500ms.
- VDD 2.0-5.5V: runs happily on 3V3.

### SKQUCAA010 joystick (Alps SKQU series catalog)
- SNAP-IN THROUGH-HOLE variant; datasheet figures assume 1.6mm PCB ->
  board thickness frozen at 1.6mm.
- Footprint: 2 columns 10.3mm apart, 3 holes each; outer 4 holes ø1.2,
  middle 2 ø1.0; 6.5mm outer span, middle row offset 0.45mm; stem
  rotation center offset 1.23mm (fab-layer mark).
- Circuit: A(1) B(2) C(3) directions, Common(4), D(5), Center(6).
- Min rating 10uA/1V: 3.3V GPIO + pull-up (~330uA wetting) is compliant.
- Wave/dip solder 260C 5s max: matches JLC THT process.

## Pipeline (mirrors NeuralCard)

gen_schematic.py -> netlist -> place_pcb.py (plate-style layout, silk) ->
freerouting -> stitch/verify -> DRC -> fab export. Renders in render/.

## Status

- [x] Research + plan (PLAN.md)
- [x] Parts verified at JLCPCB
- [x] Libraries pulled (10/11)
- [x] Custom footprints drawn (joystick THT, touch pad, SWD pads)
- [x] Schematic complete, ERC 0 errors, 69 components, custom symbols
- [x] PCB placement + layout
- [x] Routing + DRC (see below)
- [ ] Fab outputs
- [ ] QMK firmware
- [ ] Host daemon + simulator (phase 0 track, can precede hardware)

## Routing & verification status (2026-07-20)

- [x] Fully routed: 131/131 nets (freerouting 130um signal / 0.25mm power where
  clearance allows, 500/300um vias) + hand-finished USB D- tie (F.Cu crossover
  at connector, interleaved-pad topology unroutable by autorouter)
- [x] DRC: 0 clearance / 0 shorts / 0 crossings / 0 edge violations
- [x] All GND pads connected (zone clearance 0.2mm, 70+ stitching vias);
  5 padless fill shards remain as cosmetic warnings
- [x] Real 3D models on every physical part incl. ALPS SKQUCAA010 (sourced
  from Sheepypad OSS project, scale 0.4 / rotate -90,0,180), paths via KIPRJMOD
- [x] Courtyards rebuilt for U1 + 12 hot-swap sockets (easyeda2kicad imports
  were self-intersecting); courtyards_overlap downgraded to warning: LED/cap
  nesting under keyswitches is by design
- [x] Silk texts relocated collision-free; 3D renders verified top+bottom
- [x] 3D keys: Kailh Choc v1 switch bodies + keycaps on all 12 keys, placed
  on F.Cu carrier footprints (KEY1-12, padless, excluded from BOM/pos) so
  they render on the user-facing top face opposite the back-side sockets
  (model: m-lego/m65 ChocV1.wrl + keycap, via KIPRJMOD)
- Known accepted: USB-C factory pad gaps 0.10mm (board min_clearance 0.1),
  copper-to-edge rule 0.3mm (JLC minimum)

## V2 PowerDeck (two-deck architecture, per user 2026-07-20)

V2 = this V1 board as the upper deck + a separate lower deck with Qi charging
+ battery, magnetic pogo attach. Spec:
~/kicad-projects/agentdeck-powerdeck/DESIGN.md. To make a V1 board
V2-ready (optional, only if building V2): add 4 pogo-target pads
(2xVBUS/2xGND) on B.Cu + 4 silk-marked magnet zones. Ideal-diode lives on
the PowerDeck, so V1 needs no electrical change. V1 ships standalone as-is.

## 4-layer revision + mounting holes (2026-07-20)

Case-mounting revision (user chose 4-layer to fit screw holes):
- [x] Converted to 4-layer stackup: F.Cu (signal), In1.Cu (solid GND plane),
  In2.Cu (GND/power), B.Cu (signal). Standard inner-layer names are REQUIRED , 
  custom names (GND_plane/PWR_plane) break freerouting SES via-layer mapping on
  import (silent 78-net connectivity loss). Lesson logged.
- [x] 4x M2.5 corner mounting holes at rounded-corner arc centers (6,6),(84,6),
  (6,84),(84,84) with 3.0mm no-copper keepouts. C16 + SW13(BOOT) relocated out
  of the bottom keepouts.
- [x] 209/213 nets routed on 4 layers; GND flood on all 4 layers; 0 clearance /
  short / edge / hole violations.
- [ ] 4 RP2040 QFN-escape nets unrouted: ENC_B, K4, K6, RUN. Freerouting cannot
  close these in ANY config tried (2-layer, 4-layer, 20+ seeds, incremental) , 
  the 0.4mm-pitch escape channels next to U1 are saturated. These need KiCad's
  interactive push-and-shove router (~10 min) or a U1 pin reassignment. This is
  an autorouter limitation, not a placement error.

Backups: /tmp/cm_4layer_good.kicad_pcb (this state),
/tmp/cm_2layer_holes.kicad_pcb (2-layer w/ holes, K2 unrouted),
/tmp/cm_preholes.kicad_pcb (2-layer 131/131, no holes).

## Routing progress update (2026-07-20, component-move optimization)

Pushed from 4 unrouted -> 1 by relocating components to open the RP2040 escape:
- Moved decoupling ring (C5,C6,C7,C8,C10,C11) + D14,C30 out of U1's escape edges.
- 4-layer, GND plane on In1, GND flood F/In2/B; 110um traces, 0.5mm vias.
- 212/213 nets routed, 0 clearance/short/edge/hole violations, holes + switch bodies in.

REMAINING: QSPI_SD0 (flash bus line 6 of 6). At the physical escape limit of the
RP2040's 0.4mm-pitch QSPI cluster: all 6 lines converge in a ~2mm region that is
saturated on B.Cu, In1, and In2 simultaneously. Freerouting fits 5; the 6th cannot
via-escape cleanly. Verified across trace widths (100/110/130um), via sizes
(0.4/0.5mm), 6 component relocations, U2 repositioning, and 60+ routing runs.
NEEDS: KiCad interactive push-and-shove router (rip-up the +3V3 bottom lane, shove
siblings, escape SD0) OR a +3V3 inner plane (blocked: freerouting hangs on poured
power-plane DSN). This is a tool limit, not a placement error.
Best board: /tmp/cm_FINAL_212.kicad_pcb

## Routing breakthrough (2026-07-20, GND-plane approach)

KEY INSIGHT that got the board fully connected: exclude GND (biggest net, ~80
pads) from the freerouting netlist, route only signals+3V3, then flood GND on
ALL 4 layers with via stitching. Because every layer is GND there, GND stitch
vias never punch-through-collide with signals (the fatal flaw of a +3V3-only
plane). Also excludes the +3V3 bottom-lane congestion that blocked QSPI_SD0.

Result: ALL 213 nets connected on 4-layer (F/B signals, In1/In2 = GND flood +
+3V3 traces), 4 mounting holes, BOOT/C16/U3 moved clear of hole keepouts.
Board: /tmp/cm_213routed.kicad_pcb

REMAINING: 9 DRC violations, 7 of them in the joystick centre-button (JOY_CTR)
escape: 5 joystick signals + LED_DATA all exit adjacent RP2040 pins in a ~2mm
cluster; JOY_CTR is the 6th and can't via-escape without shoving neighbours.
Plus 2 pre-existing freerouting via clearances (K12 vs +3V3, K9 vs VBUS) and
2 GND island vias. All are interactive-router touchups (shove traces / nudge
vias) that headless scripting can't do cleanly.

## Board complete (2026-07-20)

**0 DRC errors, 0 unconnected, all 213 nets routed on 4 layers.**

Final recipe that worked:
1. Exclude GND from freerouting (route signals + 3V3 only), which frees massive capacity.
2. Import SES, flood GND on all 4 layers, strict-clearance stitch (rect-aware
   pad geometry: circular approximation over-blocks 0.85x0.2 QFN pads).
3. JOY_CTR (last net): 60um bump spliced into the In1 USB_DM/DP pair to open
   9um of missing clearance, then VIA-IN-PAD on U1-30 (0.3/0.15 via) with an
   F.Cu haul (2 waypoints, auto-searched with DRC-validated path checker).
4. Board constraints updated from stale 2-layer values to JLCPCB 4-layer
   capability: track 0.1, via 0.25/0.15, annular 0.05, hole-clearance 0.2,
   netclass clearance 0.13 (was self-imposed 0.2; every 'violation' was
   0.128-0.196 actual, all JLC-legal).

Deliverables: 4-layer, 4x M2.5 corner mounting holes, BOOT/C16/U3 clear of
holes, Choc switch bodies + keycaps on all 12 keys, real 3D models throughout.
Remaining DRC items are cosmetic warnings only (library padstack artifacts,
intentional courtyard nesting, silk-over-fill).
Backup: /tmp/cm_SHIPPED.kicad_pcb

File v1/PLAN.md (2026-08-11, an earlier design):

# AgentDeck: plan (no build yet)

> A desk controller for Claude Code, in the spirit of the Work Louder x OpenAI
> Codex Micro. Planning document only. Nothing here is committed to hardware.

## 1. What the Codex Micro is (research summary)

$230 limited-run macropad by Work Louder with OpenAI, launched 2026-07-15,
based on Work Louder's Creator Micro 2. Sources:
- Product page: https://worklouder.cc/codex-micro
- Tom's Hardware: https://www.tomshardware.com/peripherals/keyboards/openais-first-hardware-device-is-an-rgb-macropod-codex-micro-features-13-low-profile-keys-and-a-joystick-for-contr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
- The New Stack: https://thenewstack.io/openai-codex-micro-macropad/
- OpenAI collab page: https://openai.com/supply/co-lab/work-louder/

Spec as reported: 13 mechanical switches, 1 rotary encoder, 1 planar
joystick, 1 touch sensor, 6 programmable layers, USB-C + Bluetooth,
Mac/Windows, aluminum base + sandblasted unibody polycarbonate frame,
PBT/PC caps (32 icon + 11 solid), POM/POK switches, RGB.

## 2. Layout observed from product photos (reference/ folder)

Front face, top to bottom:

| Row | Contents |
|---|---|
| 1 | rotary dial (two-tone cap) · 2 frosted RGB agent keys · 4-way joystick (black, dashed silk outline) |
| 2 | 4 frosted RGB agent keys |
| 3 | 4 white icon keys: lightning, accept (check), reject (x), branch (arrow) |
| 4 | touch dot (black, capless) + 3 tiny aux status LEDs · wide mic bar (~2u) · cloud-face key |

Other observations: up-arrow silk legend top center; edge silk lines
"Work Louder | OpenAI 2026", "You can just build things", "Let's build";
4 hex screws through the frosted top plate; low-profile sculpted caps;
agent-key glow reads through frosted caps very evenly (diffusion is a
quality bar to match).

Default functions (reported + inferred):
- 6 agent keys = live thread status lamps (white idle / blue thinking /
  green done / amber needs input / red error); press to focus that thread;
  configurable to pinned / recent / needs-attention.
- Icon keys: accept changes, reject changes, branch thread, quick action.
- Mic bar: push-to-talk into the composer. Cloud key: ask/explain (inferred).
- Dial: scroll + select (press = confirm). Joystick: composer/UI navigation.
- Touch dot: undocumented (likely layer/wake). 6 layers over everything.

## 3. AgentDeck concept

The pitch: the six lamps answer "which of my Claude sessions needs me?"
without alt-tabbing. Claude Code is better suited than Codex here because
hooks give us every state transition natively.

### Proposed default mapping

| Control | Claude Code action |
|---|---|
| Agent key 1-6 | one Claude Code session each; LED = state; press = focus its terminal window/tmux pane |
| LED states | orange #D97757 working · white idle · amber waiting-on-permission · green done · red error · blue thinking/planning |
| Accept key | approve current permission prompt (send "y"/Enter) |
| Reject key | deny prompt (Esc) |
| Branch key | new session in current repo |
| Lightning | /compact or a user macro |
| Mic bar | hold-to-dictate (host OS dictation into the focused composer) |
| Cloud/face key | toggle plan mode (Shift+Tab) |
| Dial | scroll transcript; press = Enter |
| Joystick | pane/window navigation |
| Touch dot | acknowledge/silence notifications |

### Host integration architecture

```
Claude Code hooks (SessionStart/Stop/Notification/PreToolUse...)
        v  (hook scripts POST state)
local daemon (menu-bar or CLI; owns session<->key assignment)
        v  raw HID reports (LED states)          ^ key events
AgentDeck over USB                    terminal automation
                                 (focus window, send keys, tmux targets)
```

The daemon is the real product. The pad is a QMK device with raw HID.

## 4. Hardware architecture (options, recommendation, NOT final)

| Block | Recommended v1 | Alternatives | Why |
|---|---|---|---|
| MCU | RP2040 + QMK, USB-C only | nRF52840+ZMK (adds BT, but host->LED path is hard in ZMK); ESP32-S3 custom fw (BT+USB, most code) | QMK raw HID is proven; wireless deferred to v2 |
| Switches | Kailh Choc v1, hotswap sockets | Choc v2, Gateron LP | low profile like the original, huge cap ecosystem |
| Per-key RGB | SK6812 MINI-E x6 (agent keys) | full RGB all keys | MINI-E mounts through-plate for clean underglow-through-frost |
| Encoder | EC11 with push | -- | commodity |
| Joystick | 5-way tact (SKQUCAA-style) | PSP analog thumbstick (needs ADC + QMK pointing device) | photos show a digital 4-way rocker; digital is simpler |
| Touch | TTP223 cap-touch IC + PCB pad | MPR121 | RP2040 has no native touch |
| Aux LEDs | 3x 0603 side LEDs | -- | match the original's status trio |
| Enclosure | 3D-printed translucent resin/PETG frame + weighted printed base | CNC polycarbonate + alu (quote later; this is where the $230 goes) | print first, CNC when happy |
| Caps | MBK Choc blanks; frosted/translucent caps for the 6 agent keys; UV-printed legends | relegendable Choc caps | frosted low-profile caps are the main sourcing risk |

Draft cost target: $45-70 in parts DIY (PCB+PCBA ~$25-35, switches/caps
~$15, enclosure print ~$10) vs $230 retail. CNC enclosure would add ~$60+.

## 5. Phases and decision gates

1. **Spec freeze** (needs decisions below)
2. Schematic + layout, script-generated like NeuralCard (same pipeline:
   generator scripts, freerouting, JLCPCB assembly)
3. QMK firmware: keymap, raw HID protocol, LED driver
4. Host daemon: hook scripts + session registry + HID bridge + terminal
   automation (tmux first, then window focus on macOS)
5. Enclosure CAD + print; keycap legends
6. v2 candidates: Bluetooth (nRF52840), haptics, OLED

### Decisions needed before anything gets built

- Wireless in v1, or USB-C only? (recommend USB-only)
- tmux-based session switching or macOS window focus? (recommend tmux)
- Same 4x4-ish footprint as the original, or bigger caps/grid?
- Budget ceiling, and print vs CNC for the enclosure?
- Naming: "Claude" is Anthropic's trademark. Fine as a personal project;
  don't sell it under that name. Consider "Crail Micro" (the brand orange)
  if it ever goes public.

## 6. Risks and open questions

- Frosted-cap light diffusion quality is the whole look; needs cap samples.
- Exact device dimensions unknown (est. ~90x90mm from Choc pitch in photos;
  measure when possible).
- Permission-prompt automation must respect that some prompts SHOULD be
  read; accept-key blindly sending "y" is a footgun. Daemon should only
  ack prompts it can classify.
- Voice key depends on host OS dictation; scope carefully.
- Work Louder's Input software is proprietary; nothing from it is used or
  copied. Clean-room: commodity parts + QMK + our own daemon.

## 7. Prior art: pi-codex-micro (major input)

https://github.com/jal-co/pi-codex-micro (cloned in reference/, no license
file, treat as read-only study material, don't copy code until licensed).
A TypeScript extension wiring the real Codex Micro to the pi coding agent.
What it teaches us:

1. **The input side needs no custom protocol.** They drive everything by
   mapping the Micro's controls to plain keystrokes (enter, escape,
   ctrl+alt+X chords) that the agent's own keybindings catch. Our daemon
   can start the same way with Claude Code keybindings, and raw HID is
   only needed for the LED direction.
2. **Simulator-first works.** Their `/codex-micro sim` is a browser-based
   virtual device where every running agent session occupies an agent key
   with live state, no hardware needed. We should build the AgentDeck
   as software first: same daemon, same protocol, virtual device in a
   browser. Hardware then just replaces the mock transport.
3. **Expected HID shape of Work Louder hardware** (their protocol notes):
   QMK-style interfaces, keyboard 0x0001/0x0006, consumer 0x000C/0x0001,
   and VIA raw HID at usage page 0xFF60 usage 0x0061. Our clone should
   expose exactly this, which makes their extension trivially portable to
   our hardware later.
4. **Terminal-agnostic pane jumping matrix**: detect Zentty via
   ZENTTY_PANE_ID, tmux via TMUX_PANE, WezTerm via WEZTERM_PANE, Kitty via
   KITTY_WINDOW_ID; each session runs its own focus command. Adopt this
   design directly in our daemon.
5. **The real Codex Micro's LED protocol is undocumented**, they ship a
   mock transport waiting on reverse engineering. Our clone's advantage:
   we own the firmware, so our LED protocol is open by construction.

Plan change this implies: insert a phase 0 before hardware, build the
daemon + browser simulator against Claude Code hooks. It validates the
whole UX for zero dollars and becomes the host software the hardware needs
anyway.

## 8. Reference material collected

- reference/codex-micro-og.png (press hero, 1920x1080)
- reference/codex-micro-1..4.webp (product gallery, 2048px)
- Two user-supplied screenshots (front views, key glow states) described
  in section 2.

Still wanted: side/rear/underside photos, Creator Micro 2 teardown links,
exact dimensions, Input app screenshots for daemon UX reference.

## 9. What users complain about, and what we do differently

Sources: Work Louder's public feedback board (feedback.worklouder.cc),
HN thread on the launch (news.ycombinator.com/item?id=48923079, 92
comments), TechRadar's reaction roundup, Reddit quotes therein. The Codex
Micro itself is days old, so platform complaints come from the Creator
Micro 2 / Nomad line it's built on.

### Platform complaints (feedback board, documented bugs)

| Complaint | Evidence | AgentDeck response |
|---|---|---|
| Input app fails to detect devices (Mac M-series, several products) | multiple board posts | No proprietary configurator. QMK + standard VIA protocol; any VIA client works; config lives in a text file |
| Firmware updates break older devices, no graceful recovery | "please handle old firmware versions" post | RP2040 UF2 bootloader: hold BOOTSEL, drag a file. Unbrickable by construction |
| BT mode traps: device stays in Bluetooth when unplugged, 3-tap cycling confusion, no USB-only preference | Creator Micro V2 post | v1 is USB-only. Wireless deferred until it can be done without mode traps |
| Battery life 3 days actual vs 50 advertised | feedback board bug | No battery in v1; nothing to overpromise |
| Preset installs fail, configuration is tedious | Figma preset posts | Presets are text files in a git repo |
| Macro reliability concerns | feedback board | QMK macros are mature; daemon-side macros are scriptable and testable |

### Market reaction to the Codex Micro concept (HN/Reddit)

| Criticism | Representative take | AgentDeck response |
|---|---|---|
| Price: "$230 for 12 keys feels like a prank" | Reddit via TechRadar | DIY target $45-70; that IS the project |
| "Why is a physical object better than a window on screen?" | HN top-voted skepticism | Honest answer: glanceable ambient status + eyes-stay-on-code muscle memory. And phase 0 ships the window version (the simulator) so the hardware is an optional tier, not a gate |
| "Stream Deck is cheaper and has per-key screens" | HN | Acknowledge. Daemon abstracts the display backend, so a Stream Deck frontend can be a supported alternative later; our hardware differentiates on tactile keys, dial, per-key status semantics |
| Codex lock-in / single-vendor toy | HN | Open hardware + open protocol; daemon targets Claude Code first but state model (idle/working/needs-input/done/error) is agent-agnostic |
| Novelty that tests OpenAI hardware ops, not a tool | HN | Ship the daemon as genuinely useful software; hardware earns its place or the sim suffices |

An HN commenter also linked a r/ClaudeCode post titled "I built..." that
appears to be a DIY Claude equivalent already, locate that thread and
study it before phase 0 (open item).

Net effect on the plan: the differentiators are now explicit
requirements, text-file config, UF2 recovery, USB-first, simulator as a
first-class product, open LED protocol.

## 10. What the Claude Code community already built, and what's missing

In June 2026, r/ClaudeCode and X had a wave of DIY status-light projects
wired to Claude Code hooks (per XDA's coverage and the repos below). The
demand for ambient agent status is proven. Every existing solution covers
only half the loop:

| Existing project | What it does | What it lacks |
|---|---|---|
| claude-lamp (bobek-balinek) | Moonside BLE lamps: navy working, mango idle, purple needs input | one lamp = one session; macOS-only BLE; vendor-locked lamp; output only |
| agent-light (eternityspring) | Claude Code status light system | output only |
| mini traffic lights on monitors (the June wave) | red/amber/green per hook events | one session; output only |
| $5 smart bulb hack | amber thinking, green done | one session; output only; smart-home latency |
| Rust/eframe floating traffic light | virtual, no hardware | one session; screen real estate; output only |
| sound/ntfy notification hooks | ding on Stop/Notification | interrupt-driven, not glanceable; no way to act |
| CodeAgentSwarm | terminal manager with per-terminal color status | software only, its own terminal; no physical control |

The two structural gaps, which are exactly the Codex Micro's thesis and
this project's requirements:

1. **Everything is output-only.** A lamp tells you Claude needs input;
   you still alt-tab, find the pane, read, type. No existing project has
   the input half: press the session's key to focus it, accept/reject
   from the same hand.
2. **Everything is single-session.** The people building these are the
   multi-session crowd, yet no solution shows N sessions at once. Six
   per-session lamps is the actual unmet need.

Also worth stealing while designing the daemon: claude-lamp's hook
integration and color language (navy/mango/purple has real-world testing),
and the floating-window traffic light validates the phase-0 simulator as
a product people want even without hardware. Study repos before phase 0:
github.com/bobek-balinek/claude-lamp, github.com/eternityspring/agent-light.

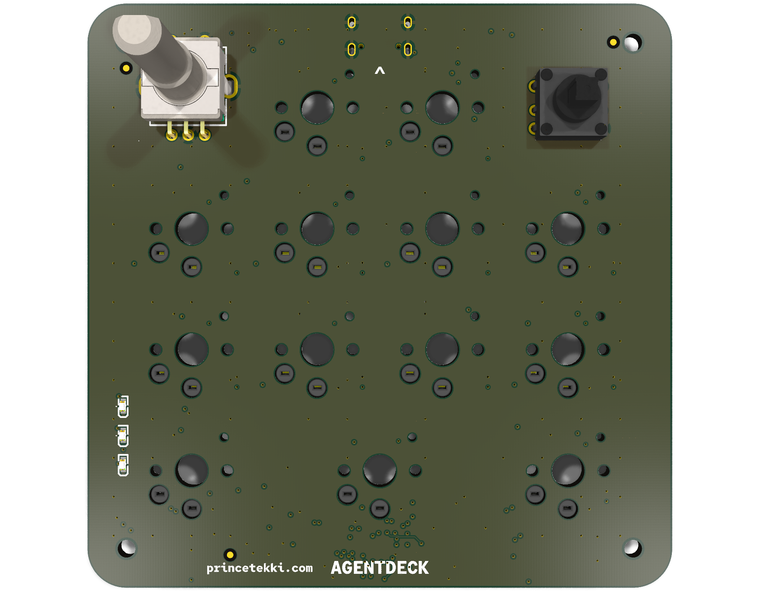
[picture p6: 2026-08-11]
docs/img/agentdeck-top.png

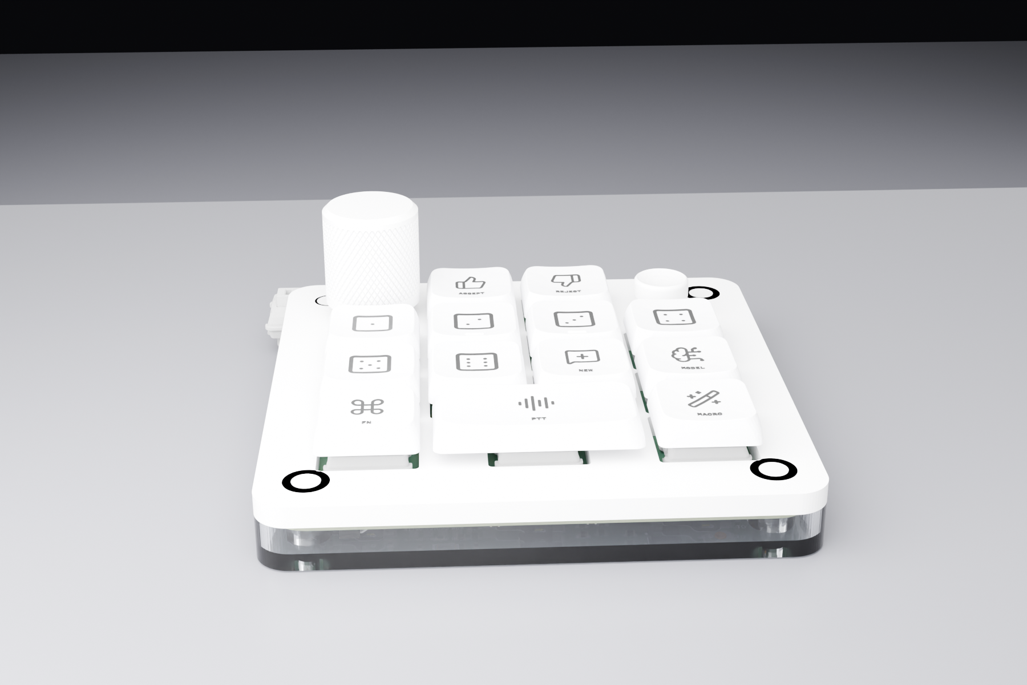
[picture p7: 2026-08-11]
docs/img/agentdeck-clear-bottom.png

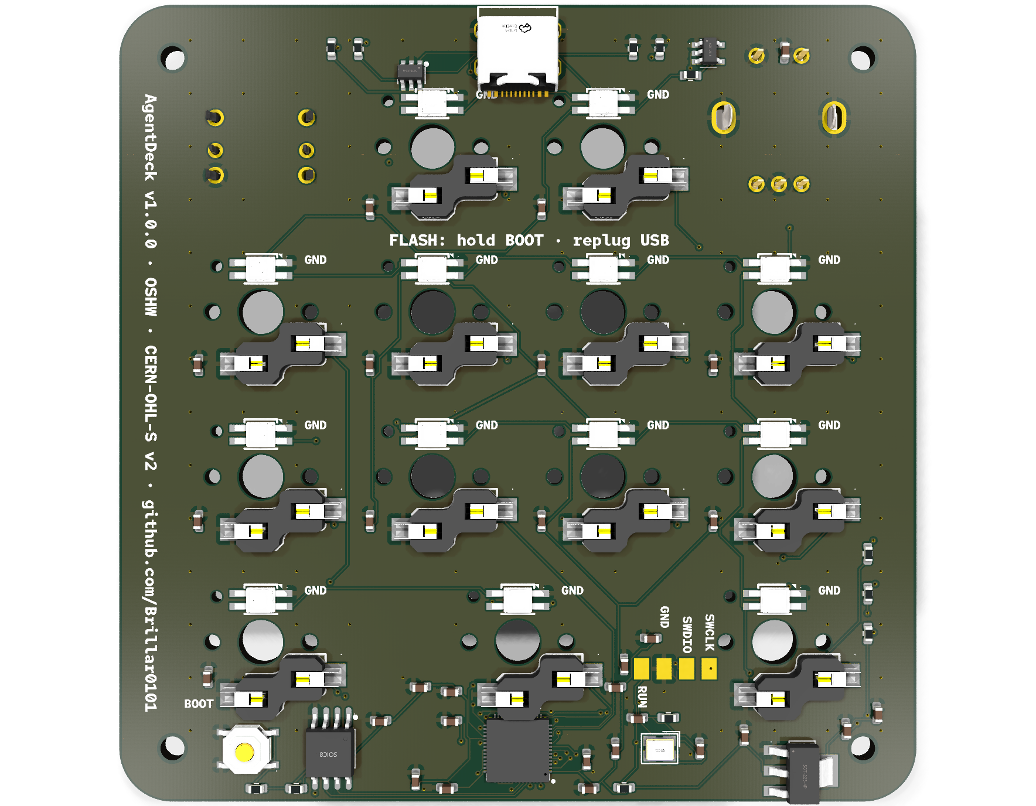
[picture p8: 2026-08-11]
docs/img/agentdeck-bottom.png

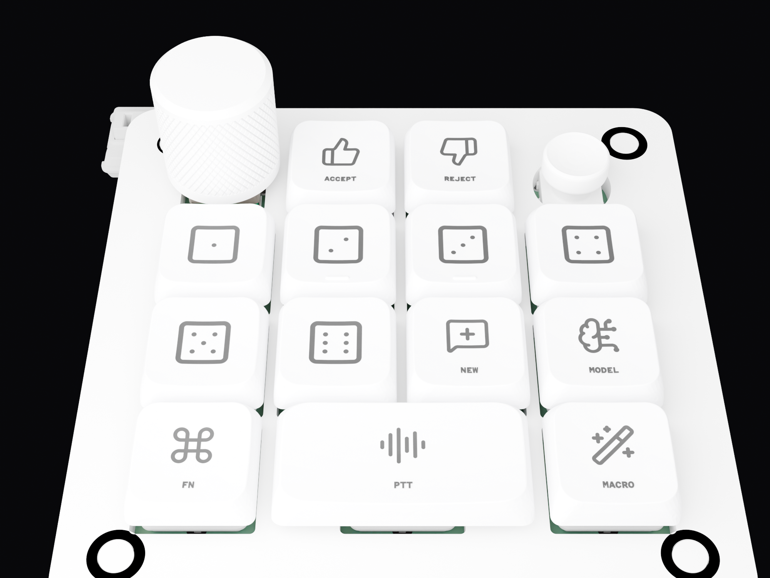
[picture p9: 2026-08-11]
docs/img/agentdeck-keys.png

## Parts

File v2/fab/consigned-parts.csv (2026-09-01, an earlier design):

Designator | Value | Footprint | Note
J3 | ProgPads 3V3/TX/GND/RX | ProgPads_1x4 | bare prog pads, no part

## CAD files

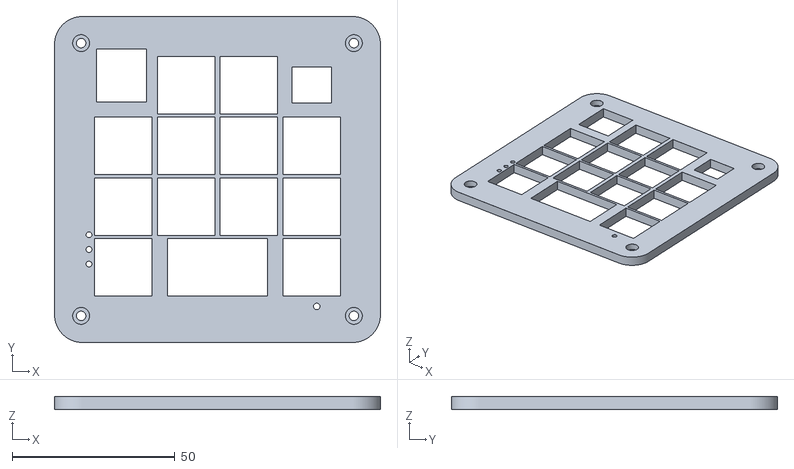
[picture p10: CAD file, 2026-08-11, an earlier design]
v1/enclosure/case-top-lid.stl
100.2 x 100.2 x 3.90

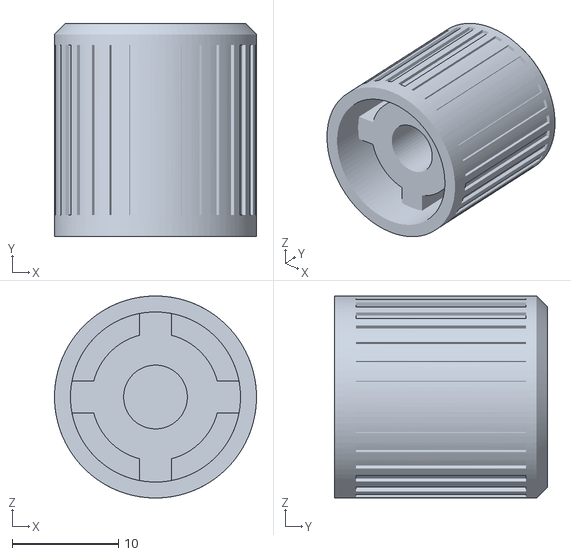
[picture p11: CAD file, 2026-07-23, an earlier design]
v1/enclosure/encoder/d19h20-slit-encoder-knobs-champfered-top.stl
19.0 x 20.0 x 19.0

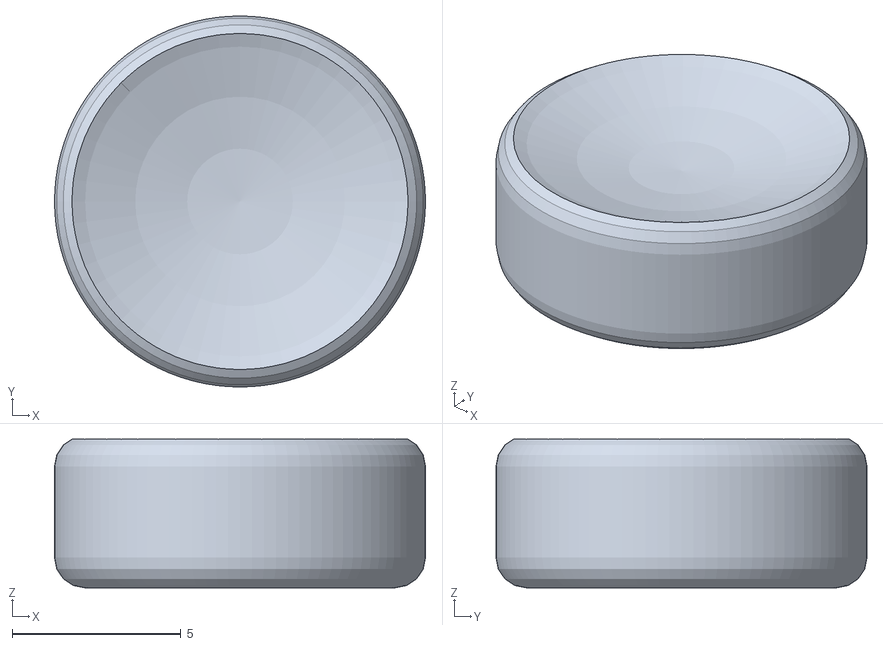
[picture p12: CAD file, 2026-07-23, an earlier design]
v1/enclosure/joystick/JoyCap.stl
11.0 x 11.0 x 4.41

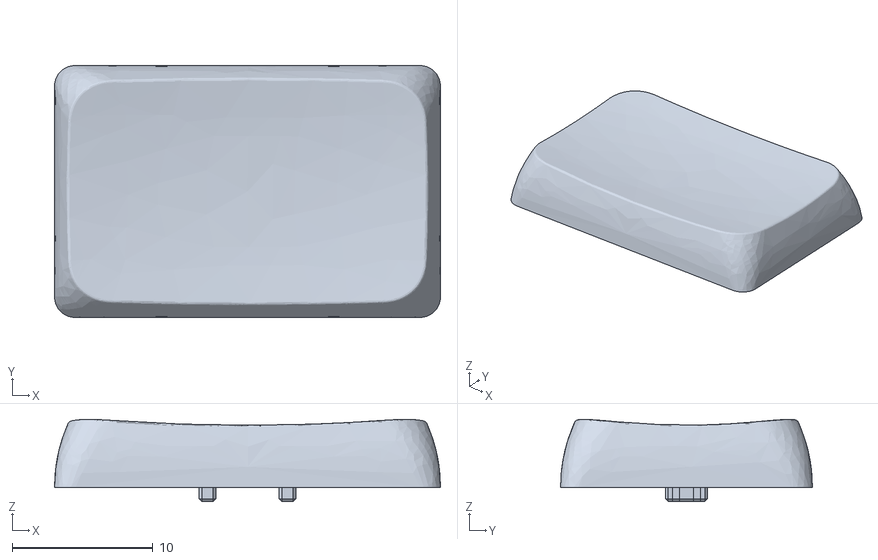
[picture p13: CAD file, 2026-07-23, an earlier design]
v1/enclosure/keycaps/cap-large.stl
27.4 x 17.9 x 5.84

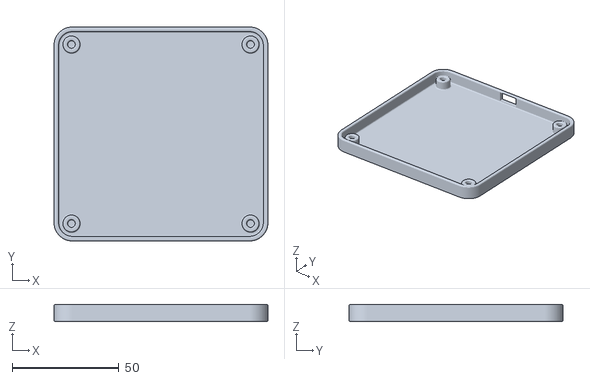
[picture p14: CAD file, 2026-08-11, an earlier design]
v1/enclosure/case-bottom.stl
100.2 x 100.2 x 8.00

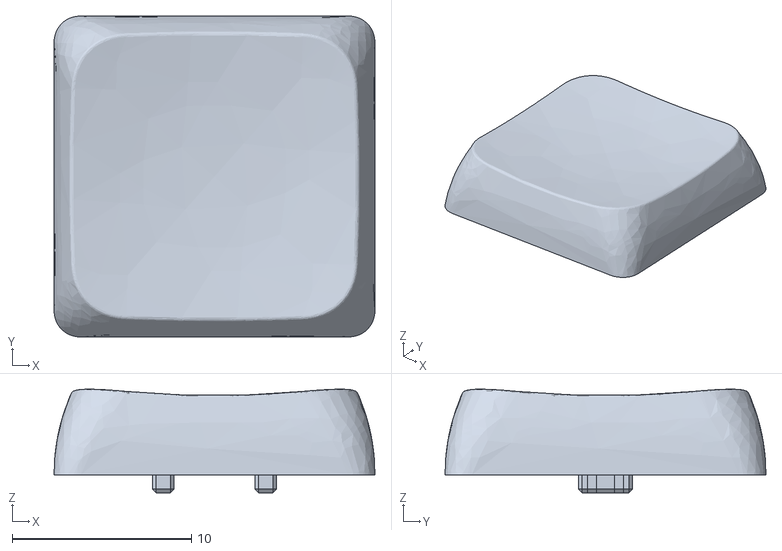
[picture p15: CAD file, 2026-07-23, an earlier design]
v1/enclosure/keycaps/cap-normal.stl
17.9 x 17.9 x 5.78

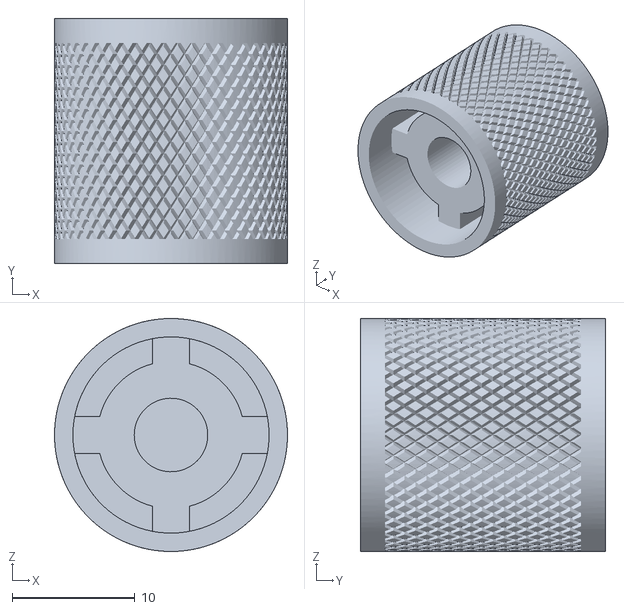
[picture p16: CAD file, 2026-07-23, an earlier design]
v1/enclosure/encoder/d19h20-knurled-encoder-knobs-flat-top.stl
19.0 x 20.0 x 19.0

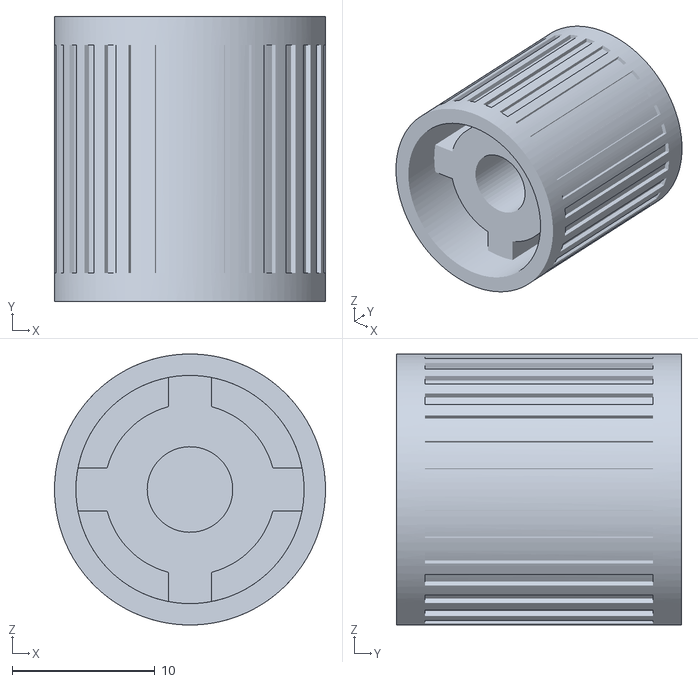
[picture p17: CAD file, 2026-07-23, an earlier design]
v1/enclosure/encoder/d19h20-slit-encoder-knobs-flat-top.stl
19.0 x 20.0 x 19.0

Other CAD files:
v1/enclosure/keycaps/kailh-lp-choc-keycap-for-corne-1/Kailh Choc FunkMonk 1.5u.step
v1/enclosure/encoder/d19h20-slit-encoder-knobs-smooth-top.stl
v1/enclosure/keycaps/kailh-lp-choc-keycap-for-corne-1/Kailh Choc FunkMonk 1u.step
v1/enclosure/keycaps/cap-groove.stl
v1/enclosure/keycaps/kailh-lp-choc-keycap-for-corne-1/Kailh Choc FunkMonk home.step
v1/enclosure/encoder/d19h20-knurled-encoder-knobs-champfered-top.stl
v1/enclosure/encoder/d19h20-knurled-encoder-knobs-smooth-top.stl
v1/enclosure/AgentDeck-v2-assembled.blend
v1/enclosure/keycaps/kailh-lp-choc-keycap-for-corne-1/Kailh LP Choc FunkMonk.f3d

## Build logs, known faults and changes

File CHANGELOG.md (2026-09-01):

# Changelog

All notable changes to AgentDeck are recorded here. The board is text-based
KiCad, so each fabricated revision maps to a tagged commit: a physical board can
be traced back to the exact design it was made from.

The format loosely follows [Keep a Changelog](https://keepachangelog.com/).
Versions are hardware revisions, not software releases.

## [Unreleased]

### V2 (wireless platform, in design)
- New `v2/`: the V3 ESP32-S3 / LiPo / BLE platform recovered from history
  (pre-297fabb) and re-cut to the roadmap's 20-key 4x5 control surface.
  Row 0 is the fixed system row (INT / PTT / REC / MODE / DND).
- Touch pad removed; Alps SKQUCAA010 5-way joystick (V1 part) added on
  GPIO15/16/17/18 + GPIO1. Battery pocket regrown to 34x50 mm for a 103450
  2000 mAh cell on the right-hand strip; board stays 150x110 mm.
- Schematic, symbol lib, netlist, placement and routing are script-generated
  (`v2/tools`), ERC clean (0 errors; 72 pin-type warnings from vendor
  symbols with "unspecified" pin types).
- Stays 2-layer. The USB pair and the module decoupling comb are pre-routed
  and locked; the USB-C clearance marker is no longer exported as a router
  keepout. Links the scripted flow leaves open are hand-routed in KiCad.
- Firmware re-cut for 20 keys, 3 modes, joystick `J` lines, system-row
  roles via `K` lines, agent slots 1-8.
- Charger stays TP4056 + load-share and battery level stays ADC: BQ24074 /
  fuel-gauge parts break the hand-solder floor (recorded in ROADMAP).
- Sourcing pass against the JLCPCB assembly library (2026-09-01): every
  symbol now carries an `LCSC` field; `v2/fab/` holds the JLCPCB BOM, CPL
  and consigned-parts list. LDO swapped ME6211C33 -> RT9080-33GJ5 (stock),
  joystick swapped SKQUCAA010 (THT, unstocked) -> SKRHABE010 (SMD, C139794)
  with the JLC library footprint. STEP models for all library parts pulled
  into `v2/hardware/jlc3d` (`tools/attach_3d.py` wires them into a board).
- Removed the unbuilt V2-V4 paper designs (297fabb). The project refocuses on
  manufacturing and validating V1 before any successor is designed.

## [1.0.0] - 2026-08-11

The V1 release. Everything below was re-verified end to end: 0 DRC errors,
0 unconnected nets, 0 ERC errors. Still nothing manufactured.

### Hardware
- Board grown from 90 x 90 to 95 x 95 mm. Mounting holes moved 2 mm out
  along the corner diagonals so the screw bosses clear the switch field.
- Full reroute on the larger outline (autorouter for the bulk, interactive
  push-and-shove for the congested RP2040 escape). Copper pours expanded to
  the new edge.
- USB-C moved to the top edge and nudged up; RP2040 moved 2 mm down.
- ERC clean: the USBLC6 ESD taps were re-declared as passive pins.
- BOM corrected (27R USB series resistors, was a 27k part number) and
  extended with the case fasteners: M2.5 x 8 button-head screws, brass
  heat-set inserts, printed cover caps.

### Enclosure
- Case is now parametric: `v1/enclosure/src/generate_case.py` builds both
  shells and the cover caps from measured board geometry. Watertight STLs,
  screw axes coaxial with the PCB holes to 0.003 mm.
- Measured fastener stack: lid counterbore 5.2 x 2.5 mm over a 2.9 mm shaft,
  through the 2.7 mm PCB hole, into a 4.0 mm OD x 5.0 mm heat-set insert.
- USB access is a side port through the tray wall (the connector hangs below
  the board), sized for the plug plus a slim cable overmould.
- 0.6 mm edge bevels so printed parts read as moulded.
- Keycaps carry Lucide icon decals (dice for the agent keys, thumbs up/down
  for accept/reject); all text legends removed. Encoder and joystick caps
  are white.

### Docs
- Photoreal render pipeline and reference renders under `docs/img/`.
- README restructured for the release.

## [0.1.0] - 2026-07-24

First complete, DRC-clean revision. Nothing has been manufactured or
hardware-verified yet.

### Hardware
- 90 x 90 mm 4-layer PCB, fully routed, 0 DRC errors.
- 13 Kailh Choc hot-swap keys with per-key SK6812MINI-E reverse-mount RGB.
- EC11 rotary encoder and Alps SKQUCAA010 5-way joystick.
- RP2040 with W25Q128 flash, USB-C, BOOT button, SWD pads.
- All 13 LEDs positioned under their key caps (4.8 mm north of each switch
  pole hole), so light shines up through the cap rather than into the row gap.

### Firmware
- CircuitPython firmware for all 13 keys, encoder, joystick, and the LED chain.
- Six agent keys show live agent state by colour; command keys send Ctrl+Alt
  chords; FN layer key.

### Host
- `host/agentdeck_bridge.py` maps Claude Code hooks to agent-key colours.

### Enclosure
- Two-part printable case (bottom + plate lid) plus cover plugs, modelled in
  Blender and exported to STL. Not yet printed.

### Fab
- Gerbers, drill, BOM, and CPL generated for JLCPCB.

[Unreleased]: https://github.com/Brillar0101/agentdeck/compare/v1.0.0...HEAD
[1.0.0]: https://github.com/Brillar0101/agentdeck/compare/v0.1.0...v1.0.0
[0.1.0]: https://github.com/Brillar0101/agentdeck/releases/tag/v0.1.0

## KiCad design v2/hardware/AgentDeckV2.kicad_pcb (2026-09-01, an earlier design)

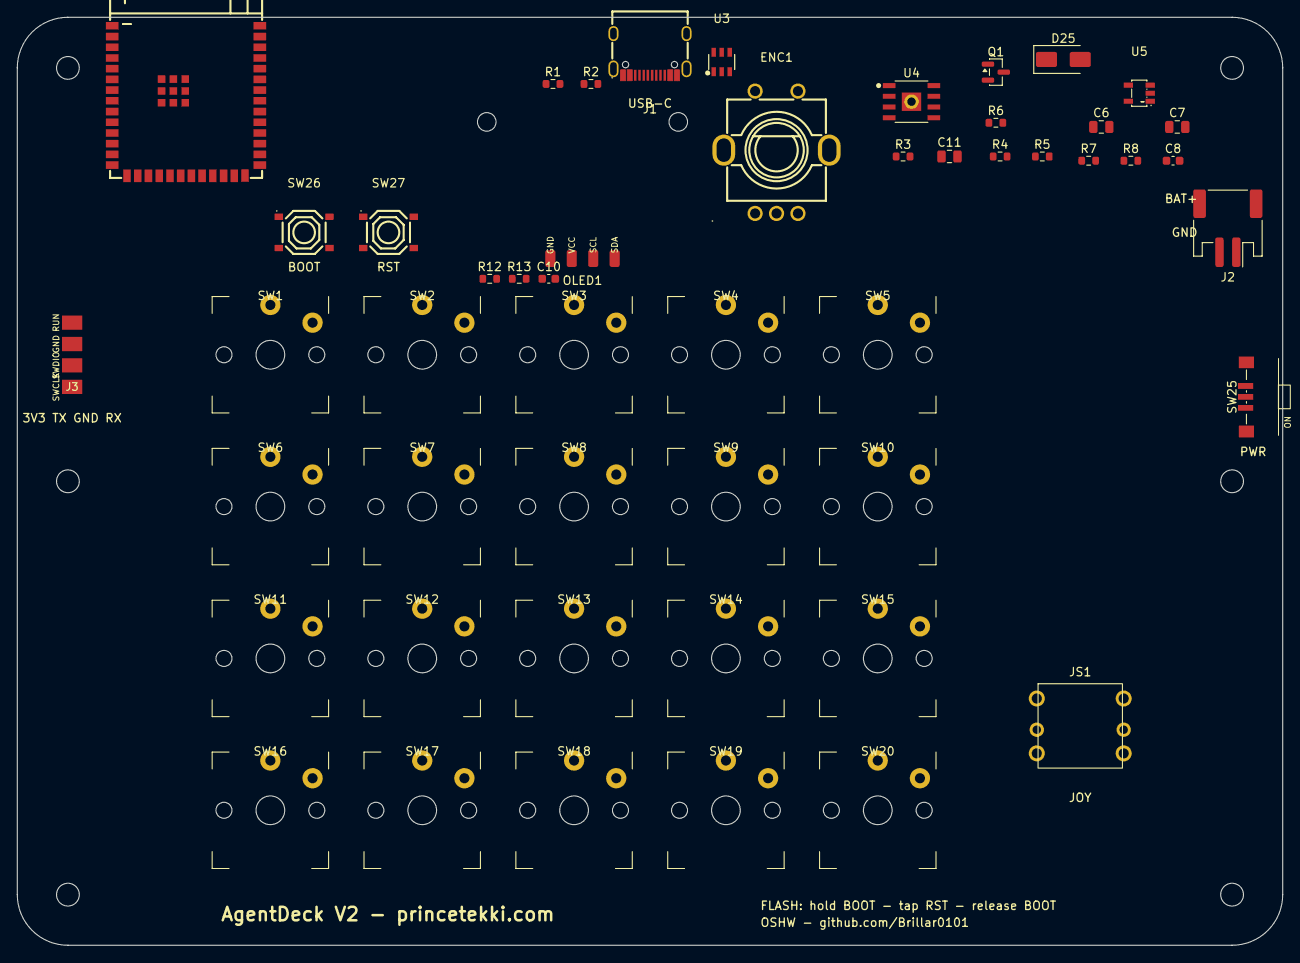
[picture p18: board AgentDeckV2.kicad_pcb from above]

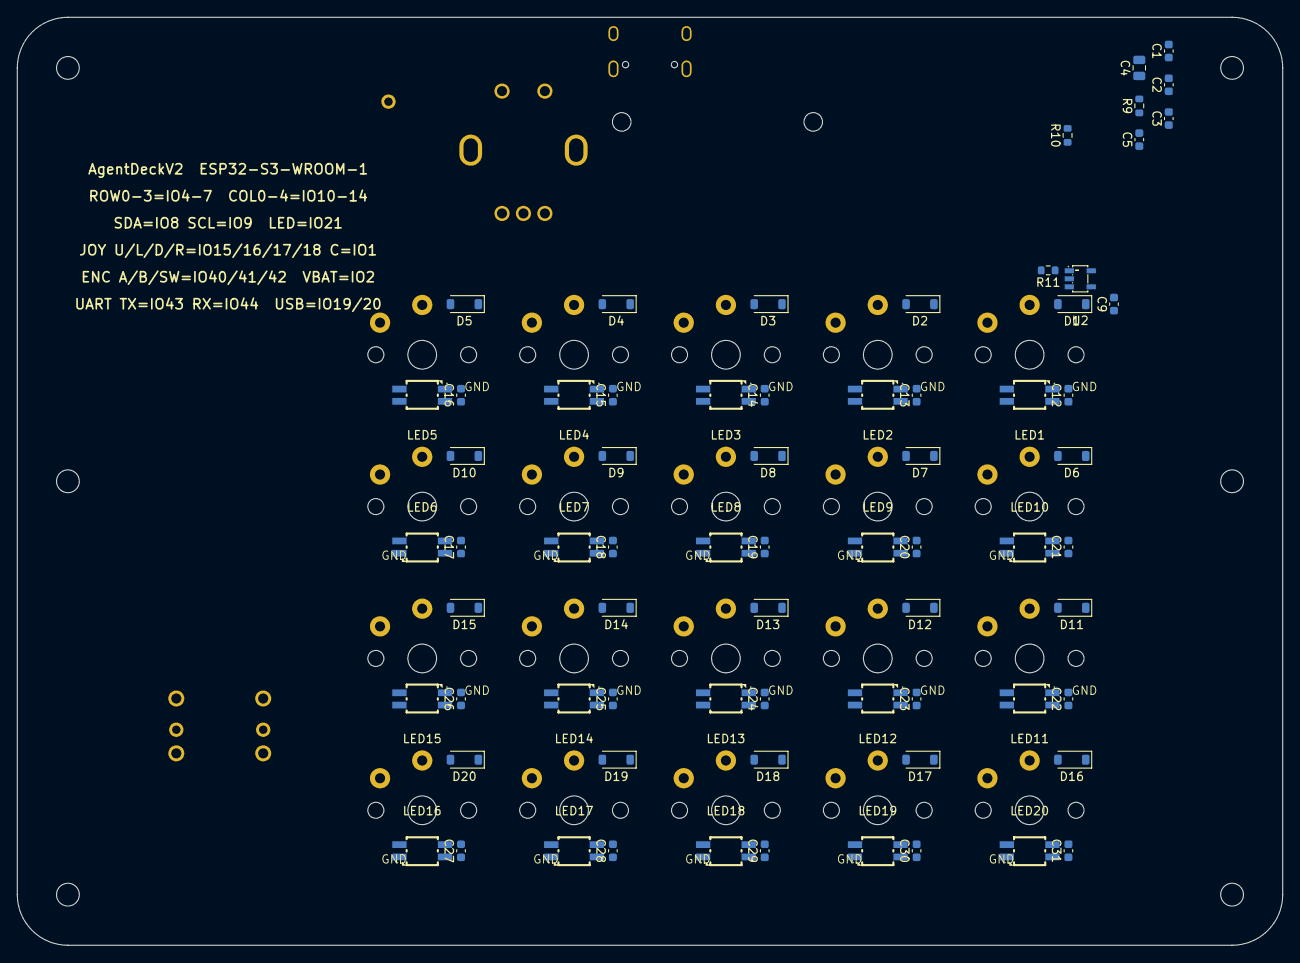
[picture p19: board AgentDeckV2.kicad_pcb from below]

Board: 2 copper layers, 150.0 x 110.0 mm, 126 parts (70 on the bottom side), 81 nets, no tracks yet.

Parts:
C1, C2, C3, C5, C8, C9, C10, C12, C13, C14, C15, C16, C17, C18, C19, C20, C21, C22, C23, C24, C25, C26, C27, C28, C29, C30, C31: C_0603_1608Metric
C4, C6, C7, C11: C_0805_2012Metric
D1, D2, D3, D4, D5, D6, D7, D8, D9, D10, D11, D12, D13, D14, D15, D16, D17, D18, D19, D20: D_SOD-123
D25: D_SMA
ENC1: SW-TH_EC11E1820402
J1: USB-C_SMD-TYPE-C-31-M-12_1
J2: JST_PH_S2B-PH-SM4-TB_1x02-1MP_P2.00mm_Horizontal
J3: SWD; ProgPads_1x4
JS1: SKQUCAA010
LED1, LED2, LED3, LED4, LED5, LED6, LED7, LED8, LED9, LED10, LED11, LED12, LED13, LED14, LED15, LED16, LED17, LED18, LED19, LED20: LED-SMD_4P-L3.2-W2.8-LS5.9_SK6812MINI-E
MH1, MH2, MH3, MH4, MH5, MH6: M2.5; MountingHole_M2_5
OLED1: OLED_HS96L03
Q1: SOT-23
R1, R2, R3, R4, R5, R6, R7, R8, R9, R10, R11, R12, R13: R_0603_1608Metric
SW1, SW2, SW3, SW4, SW5, SW6, SW7, SW8, SW9, SW10, SW11, SW12, SW13, SW14, SW15, SW16, SW17, SW18, SW19, SW20: ChocV1_Direct
SW25: MSK12C02
SW26, SW27: SW-SMD_4P-L5.1-W5.1-P3.70-LS6.5-TL_H1.5
U1: WIRELM-SMD_ESP32-S3-WROOM-1
U2, U5: SOT-23-5_L3.0-W1.7-P0.95-LS2.8-BR
U3: SOT-23-6_L2.9-W1.6-P0.95-LS2.8-BL
U4: ESOP-8_TP4056

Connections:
+3V3: C1.1, C2.1, C3.1, C4.1, C7.1, C10.1, J3.1, OLED1.2, R9.1, R10.1, R12.1, R13.1, U1.2, U5.5
BAT+: J2.1, Q1.3, R7.1, U4.5
CC1: J1.A5, R1.1
CC2: J1.B5, R2.1
CHRG: R4.1, U4.7
CHRG_SNS: R4.2, U1.24
COL0: SW1.1, SW6.1, SW11.1, SW16.1, U1.18
COL1: SW2.1, SW7.1, SW12.1, SW17.1, U1.19
COL2: SW3.1, SW8.1, SW13.1, SW18.1, U1.20
COL3: SW4.1, SW9.1, SW14.1, SW19.1, U1.21
COL4: SW5.1, SW10.1, SW15.1, SW20.1, U1.22
EN: C5.1, R9.2, SW27.1, SW27.3, U1.3
ENC_A: ENC1.A, U1.33
ENC_B: ENC1.B, U1.34
ENC_SW: ENC1.D, U1.35
GND: C1.2, C2.2, C3.2, C4.2, C5.2, C6.2, C7.2, C8.2, C9.2, C10.2, C11.2, C12.2, C13.2, C14.2, C15.2, C16.2, C17.2, C18.2, C19.2, C20.2, C21.2, C22.2, C23.2, C24.2, C25.2, C26.2, C27.2, C28.2, C29.2, C30.2, C31.2, ENC1.C, ENC1.E, ENC1.F, ENC1.G, J1.1, J1.2, J1.3, J1.4, J1.A1B12, J1.B1A12, J2.2, J3.3, JS1.4, LED1.1, LED2.1, LED3.1, LED4.1, LED5.1, LED6.1, LED7.1, LED8.1, LED9.1, LED10.1, LED11.1, LED12.1, LED13.1, LED14.1, LED15.1, LED16.1, LED17.1, LED18.1, LED19.1, LED20.1, OLED1.1, R1.2, R2.2, R3.2, R6.2, R8.2, SW26.2, SW26.4, SW27.2, SW27.4, U1.1, U1.40, U1.41, U2.1, U2.3, U3.2, U4.1, U4.3, U5.2
IO0: R10.2, SW26.1, SW26.3, U1.27
JOY_CTR: JS1.6, U1.39
JOY_DOWN: JS1.3, U1.10
JOY_LEFT: JS1.2, U1.9
JOY_RIGHT: JS1.5, U1.11
JOY_UP: JS1.1, U1.8
KD1: D1.2, SW1.2
KD2: D2.2, SW2.2
KD3: D3.2, SW3.2
KD4: D4.2, SW4.2
KD5: D5.2, SW5.2
KD6: D6.2, SW6.2
KD7: D7.2, SW7.2
KD8: D8.2, SW8.2
KD9: D9.2, SW9.2
KD10: D10.2, SW10.2
KD11: D11.2, SW11.2
KD12: D12.2, SW12.2
KD13: D13.2, SW13.2
KD14: D14.2, SW14.2
KD15: D15.2, SW15.2
KD16: D16.2, SW16.2
KD17: D17.2, SW17.2
KD18: D18.2, SW18.2
KD19: D19.2, SW19.2
KD20: D20.2, SW20.2
LED_D1: LED1.2, R11.2
LED_D2: LED1.4, LED2.2
LED_D3: LED2.4, LED3.2
LED_D4: LED3.4, LED4.2
LED_D5: LED4.4, LED5.2
LED_D6: LED5.4, LED6.2
LED_D7: LED6.4, LED7.2
LED_D8: LED7.4, LED8.2
LED_D9: LED8.4, LED9.2
LED_D10: LED9.4, LED10.2
LED_D11: LED10.4, LED11.2
LED_D12: LED11.4, LED12.2
LED_D13: LED12.4, LED13.2
LED_D14: LED13.4, LED14.2
LED_D15: LED14.4, LED15.2
LED_D16: LED15.4, LED16.2
LED_D17: LED16.4, LED17.2
LED_D18: LED17.4, LED18.2
LED_D19: LED18.4, LED19.2
LED_D20: LED19.4, LED20.2
LED_DATA: U1.23, U2.2
LED_DATA_BUF: R11.1, U2.4
PROG: R3.1, U4.2
ROW0: D1.1, D2.1, D3.1, D4.1, D5.1, U1.4
ROW1: D6.1, D7.1, D8.1, D9.1, D10.1, U1.5
ROW2: D11.1, D12.1, D13.1, D14.1, D15.1, U1.6
ROW3: D16.1, D17.1, D18.1, D19.1, D20.1, U1.7
RXD: J3.4, U1.36
SCL: OLED1.3, R13.2, U1.17
SDA: OLED1.4, R12.2, U1.12
STDBY: R5.1, U4.6
STDBY_SNS: R5.2, U1.25
TXD: J3.2, U1.37
USB_DM: J1.A7, J1.B7, U1.13, U3.1, U3.6
USB_DP: J1.A6, J1.B6, U1.14, U3.3, U3.4
VBAT_SNS: C8.1, R7.2, R8.1, U1.38
VBUS: C11.1, D25.2, J1.A4B9, J1.B4A9, Q1.1, R6.1, U3.5, U4.4, U4.8
VSYS: D25.1, Q1.2, SW25.2
VSYS_SW: C6.1, C9.1, C12.1, C13.1, C14.1, C15.1, C16.1, C17.1, C18.1, C19.1, C20.1, C21.1, C22.1, C23.1, C24.1, C25.1, C26.1, C27.1, C28.1, C29.1, C30.1, C31.1, LED1.3, LED2.3, LED3.3, LED4.3, LED5.3, LED6.3, LED7.3, LED8.3, LED9.3, LED10.3, LED11.3, LED12.3, LED13.3, LED14.3, LED15.3, LED16.3, LED17.3, LED18.3, LED19.3, LED20.3, SW25.1, U2.5, U5.1, U5.3

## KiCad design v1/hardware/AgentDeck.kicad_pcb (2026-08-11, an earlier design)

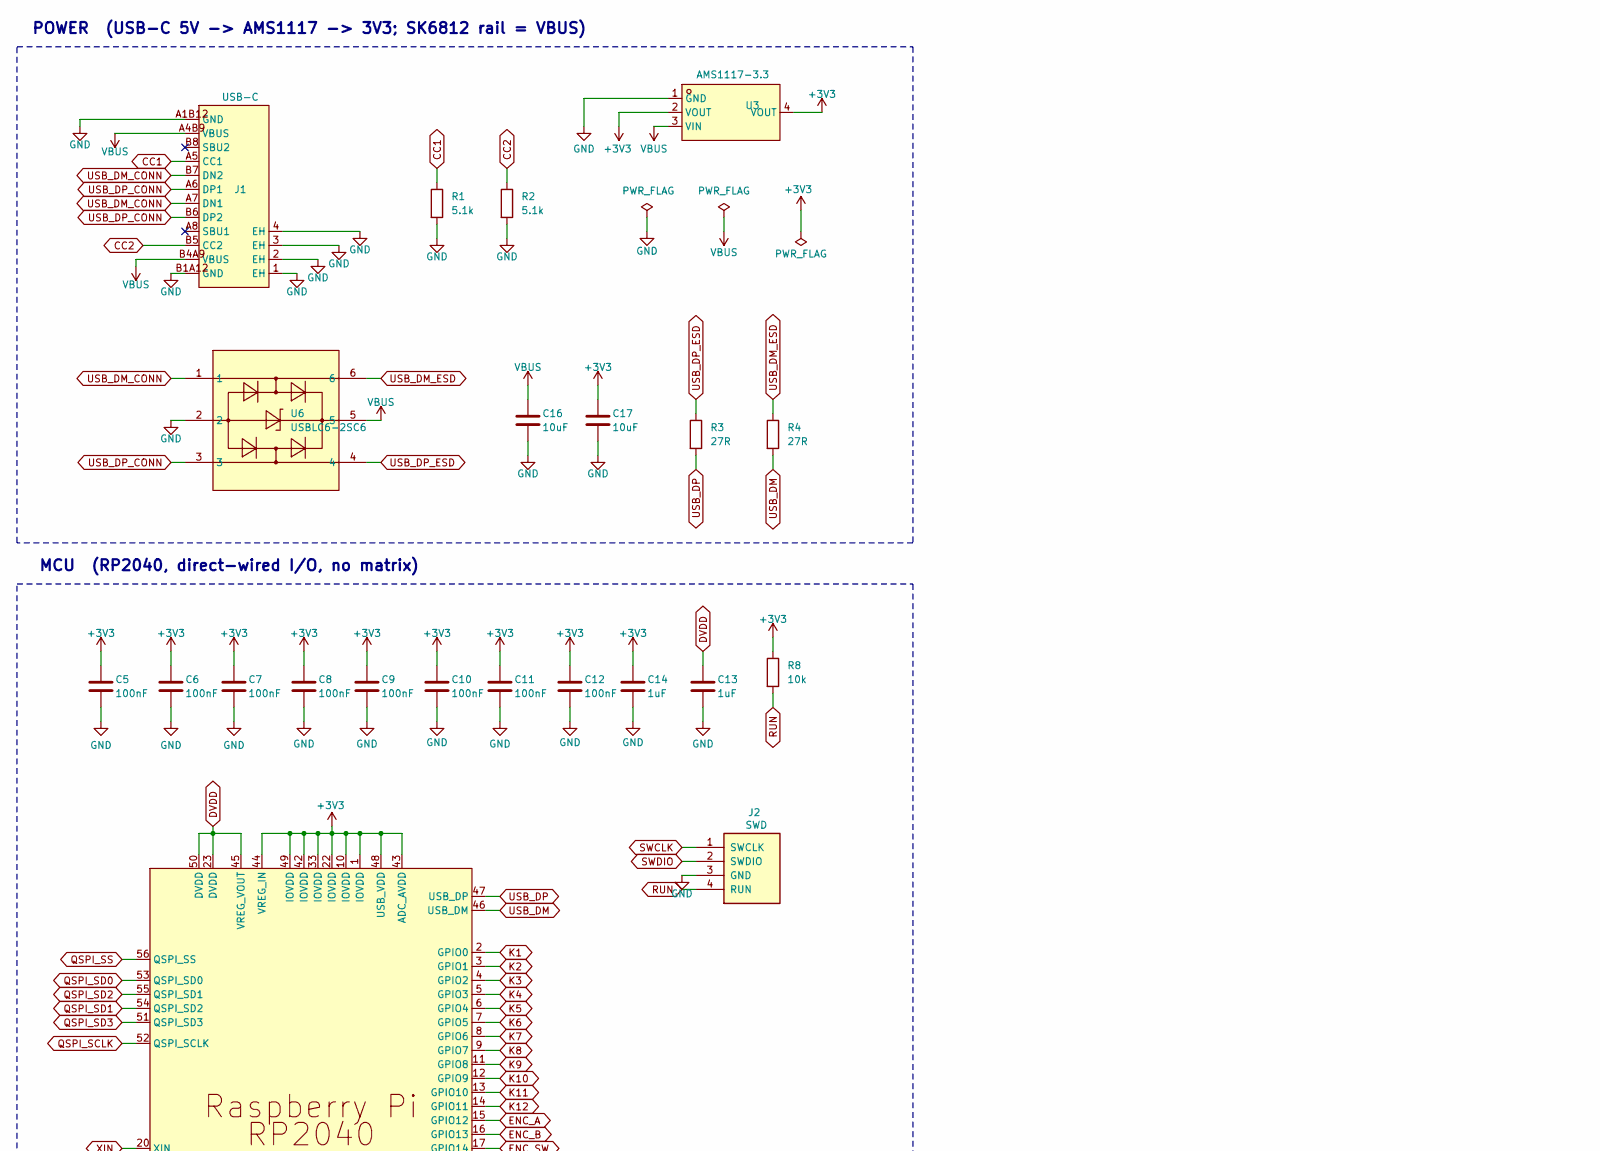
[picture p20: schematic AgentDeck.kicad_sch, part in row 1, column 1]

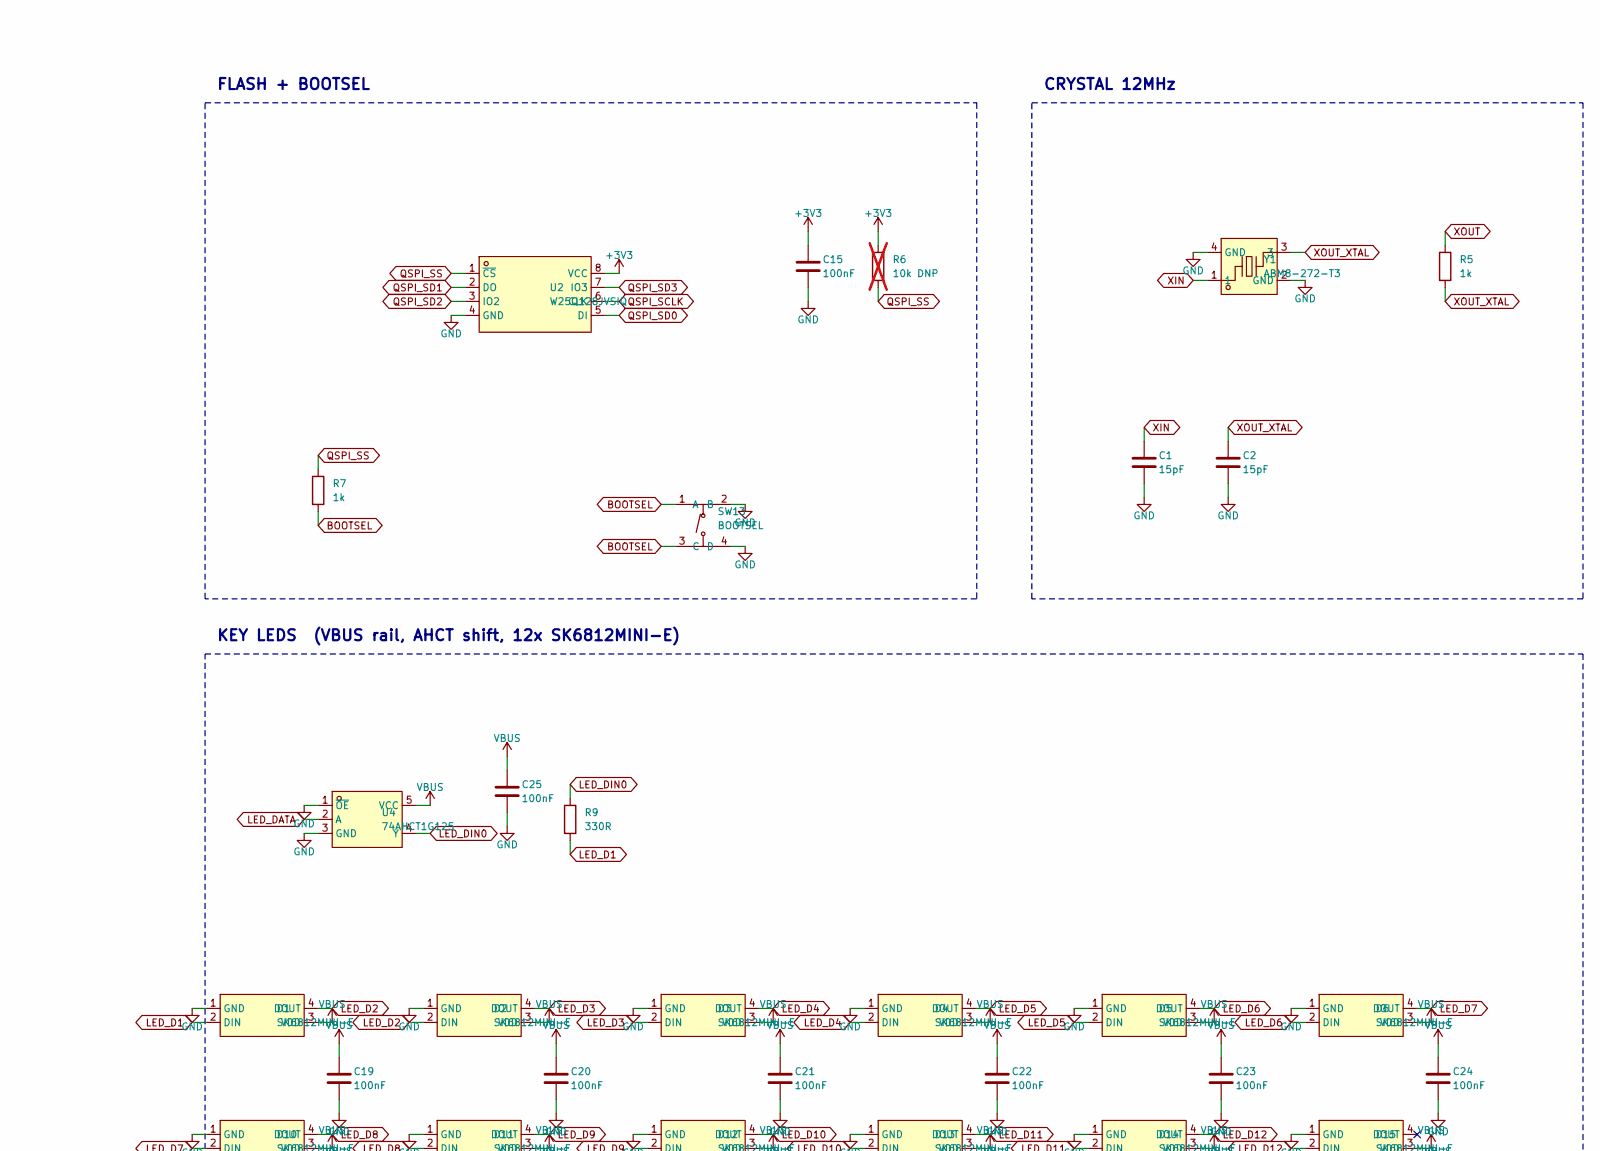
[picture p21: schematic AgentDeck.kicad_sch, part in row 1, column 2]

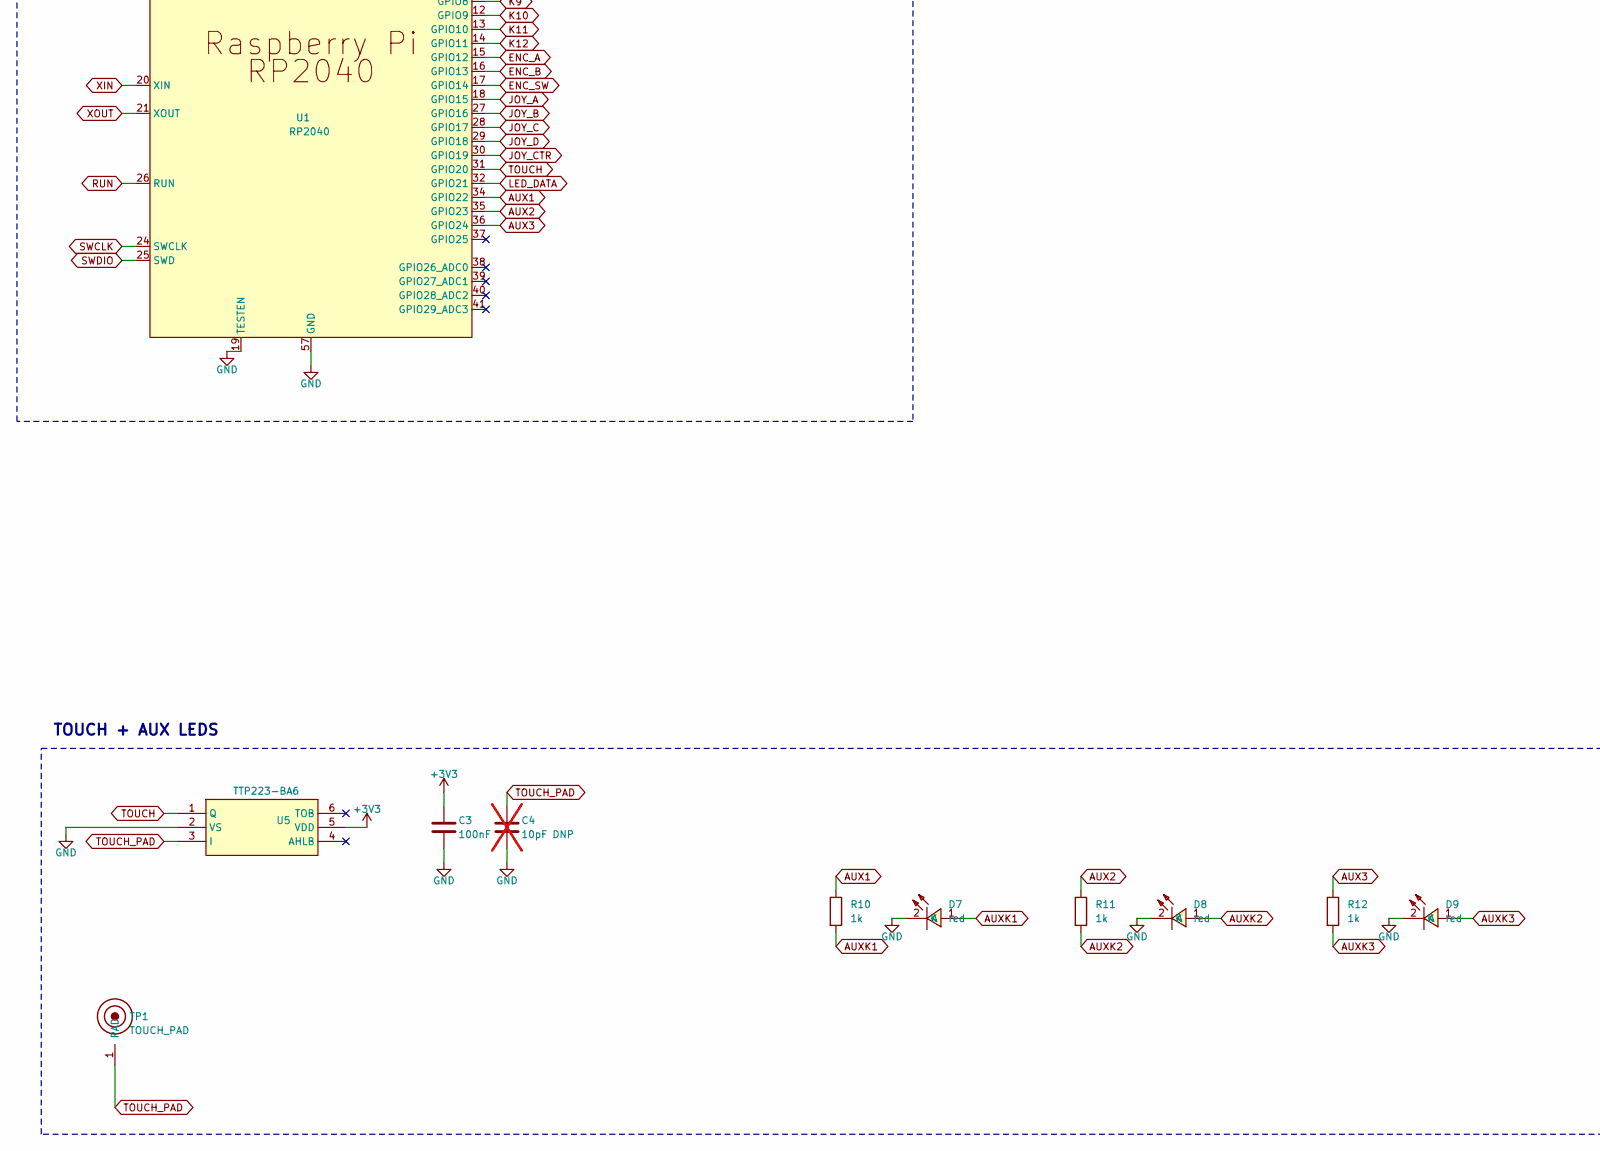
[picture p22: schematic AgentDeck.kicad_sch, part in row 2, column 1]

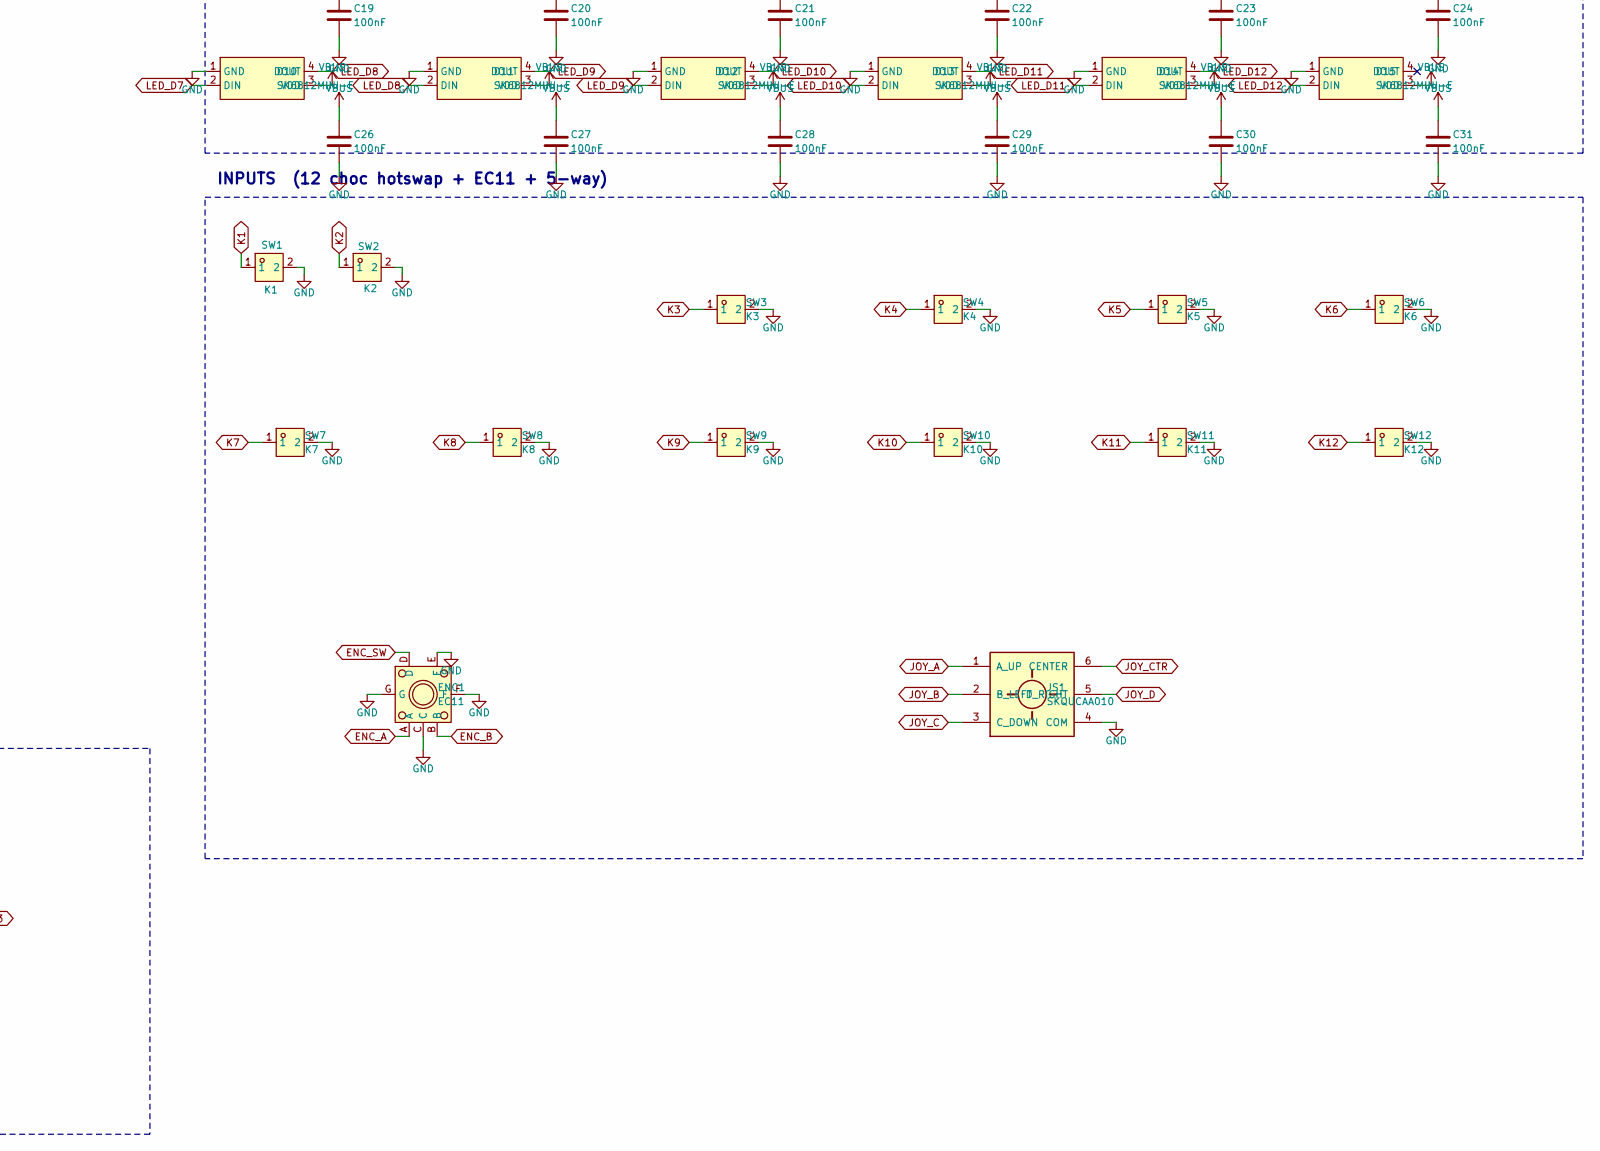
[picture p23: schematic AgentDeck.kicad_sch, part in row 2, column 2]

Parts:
C1, C2: 15pF; C_0603_1608Metric
C3, C5, C6, C7, C8, C9, C10, C11, C12, C15, C19, C20, C21, C22, C23, C24, C25, C26, C27, C28, C29, C30, C31: 100nF; C_0603_1608Metric
C4: 10pF DNP; C_0603_1608Metric; not fitted
C13, C14: 1uF; C_0603_1608Metric
C16, C17: 10uF; C_0603_1608Metric
D1, D2, D3, D4, D5, D6, D10, D11, D12, D13, D14, D15: SK6812MINI-E; LED-SMD_4P-L3.2-W2.8-LS5.9_SK6812MINI-E
D7, D8, D9: red; LED-SMD_L1.6-W0.8-R-RD
ENC1: EC11; SW-TH_EC11E1820402
J1: USB-C; USB-C_SMD-TYPE-C-31-M-12_1
J2: SWD; ProgPads_1x4
JS1: SKQUCAA010
R1, R2: 5.1k; R_0603_1608Metric
R3, R4: 27R; R_0603_1608Metric
R5, R7, R10, R11, R12: 1k; R_0603_1608Metric
R6: 10k DNP; R_0603_1608Metric; not fitted
R8: 10k; R_0603_1608Metric
R9: 330R; R_0603_1608Metric
SW1: K1; CONN-SMD_HOTPLUGPAKAGE__C9900010116
SW2: K2; CONN-SMD_HOTPLUGPAKAGE__C9900010116
SW3: K3; CONN-SMD_HOTPLUGPAKAGE__C9900010116
SW4: K4; CONN-SMD_HOTPLUGPAKAGE__C9900010116
SW5: K5; CONN-SMD_HOTPLUGPAKAGE__C9900010116
SW6: K6; CONN-SMD_HOTPLUGPAKAGE__C9900010116
SW7: K7; CONN-SMD_HOTPLUGPAKAGE__C9900010116
SW8: K8; CONN-SMD_HOTPLUGPAKAGE__C9900010116
SW9: K9; CONN-SMD_HOTPLUGPAKAGE__C9900010116
SW10: K10; CONN-SMD_HOTPLUGPAKAGE__C9900010116
SW11: K11; CONN-SMD_HOTPLUGPAKAGE__C9900010116
SW12: K12; CONN-SMD_HOTPLUGPAKAGE__C9900010116
SW13: BOOTSEL; SW-SMD_4P-L5.1-W5.1-P3.70-LS6.5-TL_H1.5
TP1: TOUCH_PAD; TouchPad_D12
U1: RP2040; LQFN-56_L7.0-W7.0-P0.4-EP
U2: W25Q128JVSIQ; SOIC-8_L5.3-W5.3-P1.27-LS8.0-BL
U3: AMS1117-3.3; SOT-223-3_L6.5-W3.4-P2.30-LS7.0-BR
U4: 74AHCT1G125; SOT-23-5_L3.0-W1.7-P0.95-LS2.8-BR
U5: TTP223-BA6; SOT-23-6_L2.9-W1.6-P0.95-LS2.8-BL
U6: USBLC6-2SC6; SOT-23-6_L2.9-W1.6-P0.95-LS2.8-BL
Y1: ABM8-272-T3; CRYSTAL-SMD_4P-L3.2-W2.5-BL

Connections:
+3V3: C3.1, C5.1, C6.1, C7.1, C8.1, C9.1, C10.1, C11.1, C12.1, C14.1, C15.1, C17.1, R6.1, R8.1, U1.1 (IOVDD), U1.10 (IOVDD), U1.22 (IOVDD), U1.33 (IOVDD), U1.42 (IOVDD), U1.43 (ADC_AVDD), U1.44 (VREG_IN), U1.48 (USB_VDD), U1.49 (IOVDD), U2.8 (VCC), U3.2 (VOUT), U3.4 (VOUT), U5.5 (VDD)
AUX1: R10.1, U1.34 (GPIO22)
AUX2: R11.1, U1.35 (GPIO23)
AUX3: R12.1, U1.36 (GPIO24)
AUXK1: D7.1 (A), R10.2
AUXK2: D8.1 (A), R11.2
AUXK3: D9.1 (A), R12.2
BOOTSEL: R7.2, SW13.1 (A), SW13.3 (C)
CC1: J1.A5 (CC1), R1.1
CC2: J1.B5 (CC2), R2.1
DVDD: C13.1, U1.23 (DVDD), U1.45 (VREG_VOUT), U1.50 (DVDD)
ENC_A: ENC1.A, U1.15 (GPIO12)
ENC_B: ENC1.B, U1.16 (GPIO13)
ENC_SW: ENC1.D, U1.17 (GPIO14)
GND: C1.2, C2.2, C3.2, C4.2, C5.2, C6.2, C7.2, C8.2, C9.2, C10.2, C11.2, C12.2, C13.2, C14.2, C15.2, C16.2, C17.2, C19.2, C20.2, C21.2, C22.2, C23.2, C24.2, C25.2, C26.2, C27.2, C28.2, C29.2, C30.2, C31.2, D1.1 (GND), D2.1 (GND), D3.1 (GND), D4.1 (GND), D5.1 (GND), D6.1 (GND), D7.2 (K), D8.2 (K), D9.2 (K), D10.1 (GND), D11.1 (GND), D12.1 (GND), D13.1 (GND), D14.1 (GND), D15.1 (GND), ENC1.C, ENC1.E, ENC1.F, ENC1.G, J1.1 (EH), J1.2 (EH), J1.3 (EH), J1.4 (EH), J1.A1B12 (GND), J1.B1A12 (GND), J2.3 (GND), JS1.4 (COM), R1.2, R2.2, SW1.2, SW2.2, SW3.2, SW4.2, SW5.2, SW6.2, SW7.2, SW8.2, SW9.2, SW10.2, SW11.2, SW12.2, SW13.2 (B), SW13.4 (D), U1.19 (TESTEN), U1.57 (GND), U2.4 (GND), U3.1 (GND), U4.1 (~OE), U4.3 (GND), U5.2 (VS), U6.2, Y1.2 (GND), Y1.4 (GND); also elsewhere on the board
JOY_A: JS1.1 (A_UP), U1.18 (GPIO15)
JOY_B: JS1.2 (B_LEFT), U1.27 (GPIO16)
JOY_C: JS1.3 (C_DOWN), U1.28 (GPIO17)
JOY_CTR: JS1.6 (CENTER), U1.30 (GPIO19)
JOY_D: JS1.5 (D_RIGHT), U1.29 (GPIO18)
K1: SW1.1, U1.2 (GPIO0)
K2: SW2.1, U1.3 (GPIO1)
K3: SW3.1, U1.4 (GPIO2)
K4: SW4.1, U1.5 (GPIO3)
K5: SW5.1, U1.6 (GPIO4)
K6: SW6.1, U1.7 (GPIO5)
K7: SW7.1, U1.8 (GPIO6)
K8: SW8.1, U1.9 (GPIO7)
K9: SW9.1, U1.11 (GPIO8)
K10: SW10.1, U1.12 (GPIO9)
K11: SW11.1, U1.13 (GPIO10)
K12: SW12.1, U1.14 (GPIO11)
LED_D1: D1.2 (DIN), R9.2
LED_D2: D1.4 (DOUT), D2.2 (DIN)
LED_D3: D2.4 (DOUT), D3.2 (DIN)
LED_D4: D3.4 (DOUT), D4.2 (DIN)
LED_D5: D4.4 (DOUT), D5.2 (DIN)
LED_D6: D5.4 (DOUT), D6.2 (DIN)
LED_D7: D6.4 (DOUT), D10.2 (DIN)
LED_D8: D10.4 (DOUT), D11.2 (DIN)
LED_D9: D11.4 (DOUT), D12.2 (DIN)
LED_D10: D12.4 (DOUT), D13.2 (DIN)
LED_D11: D13.4 (DOUT), D14.2 (DIN)
LED_D12: D14.4 (DOUT), D15.2 (DIN)
LED_D13: D15.4 (DOUT); also elsewhere on the board
LED_DATA: U1.32 (GPIO21), U4.2 (A)
LED_DIN0: R9.1, U4.4 (Y)
unnamed: C4.1, TP1.1, U5.3 (I)
QSPI_SCLK: U1.52 (QSPI_SCLK), U2.6 (CLK)
QSPI_SD0: U1.53 (QSPI_SD0), U2.5 (DI)
QSPI_SD1: U1.54 (QSPI_SD2), U2.2 (DO)
QSPI_SD2: U1.55 (QSPI_SD1), U2.3 (IO2)
QSPI_SD3: U1.51 (QSPI_SD3), U2.7 (IO3)
QSPI_SS: R6.2, R7.1, U1.56 (QSPI_SS), U2.1 (~CS)
RUN: J2.4 (RUN), R8.2, U1.26 (RUN)
SWCLK: J2.1 (SWCLK), U1.24 (SWCLK)
SWDIO: J2.2 (SWDIO), U1.25 (SWD)
TOUCH: U1.31 (GPIO20), U5.1 (Q); also elsewhere on the board
USB_DM: R4.2, U1.46 (USB_DM)
USB_DM_CONN: J1.A7 (DN1), J1.B7 (DN2), U6.1
USB_DM_ESD: R4.1, U6.6
USB_DP: R3.2, U1.47 (USB_DP)
USB_DP_CONN: J1.A6 (DP1), J1.B6 (DP2), U6.3
USB_DP_ESD: R3.1, U6.4
VBUS: C16.1, C19.1, C20.1, C21.1, C22.1, C23.1, C24.1, C25.1, C26.1, C27.1, C28.1, C29.1, C30.1, C31.1, D1.3 (VDD), D2.3 (VDD), D3.3 (VDD), D4.3 (VDD), D5.3 (VDD), D6.3 (VDD), D10.3 (VDD), D11.3 (VDD), D12.3 (VDD), D13.3 (VDD), D14.3 (VDD), D15.3 (VDD), J1.A4B9 (VBUS), J1.B4A9 (VBUS), U3.3 (VIN), U4.5 (VCC), U6.5; also elsewhere on the board
XIN: C1.1, U1.20 (XIN), Y1.1
XOUT: R5.1, U1.21 (XOUT)
XOUT_XTAL: C2.1, R5.2, Y1.3

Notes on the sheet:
POWER (USB-C 5V -> AMS1117 -> 3V3; SK6812 rail = VBUS)
CRYSTAL 12MHz
INPUTS (12 choc hotswap + EC11 + 5-way)
FLASH + BOOTSEL
TOUCH + AUX LEDS
MCU (RP2040, direct-wired I/O, no matrix)
KEY LEDS (VBUS rail, AHCT shift, 12x SK6812MINI-E)

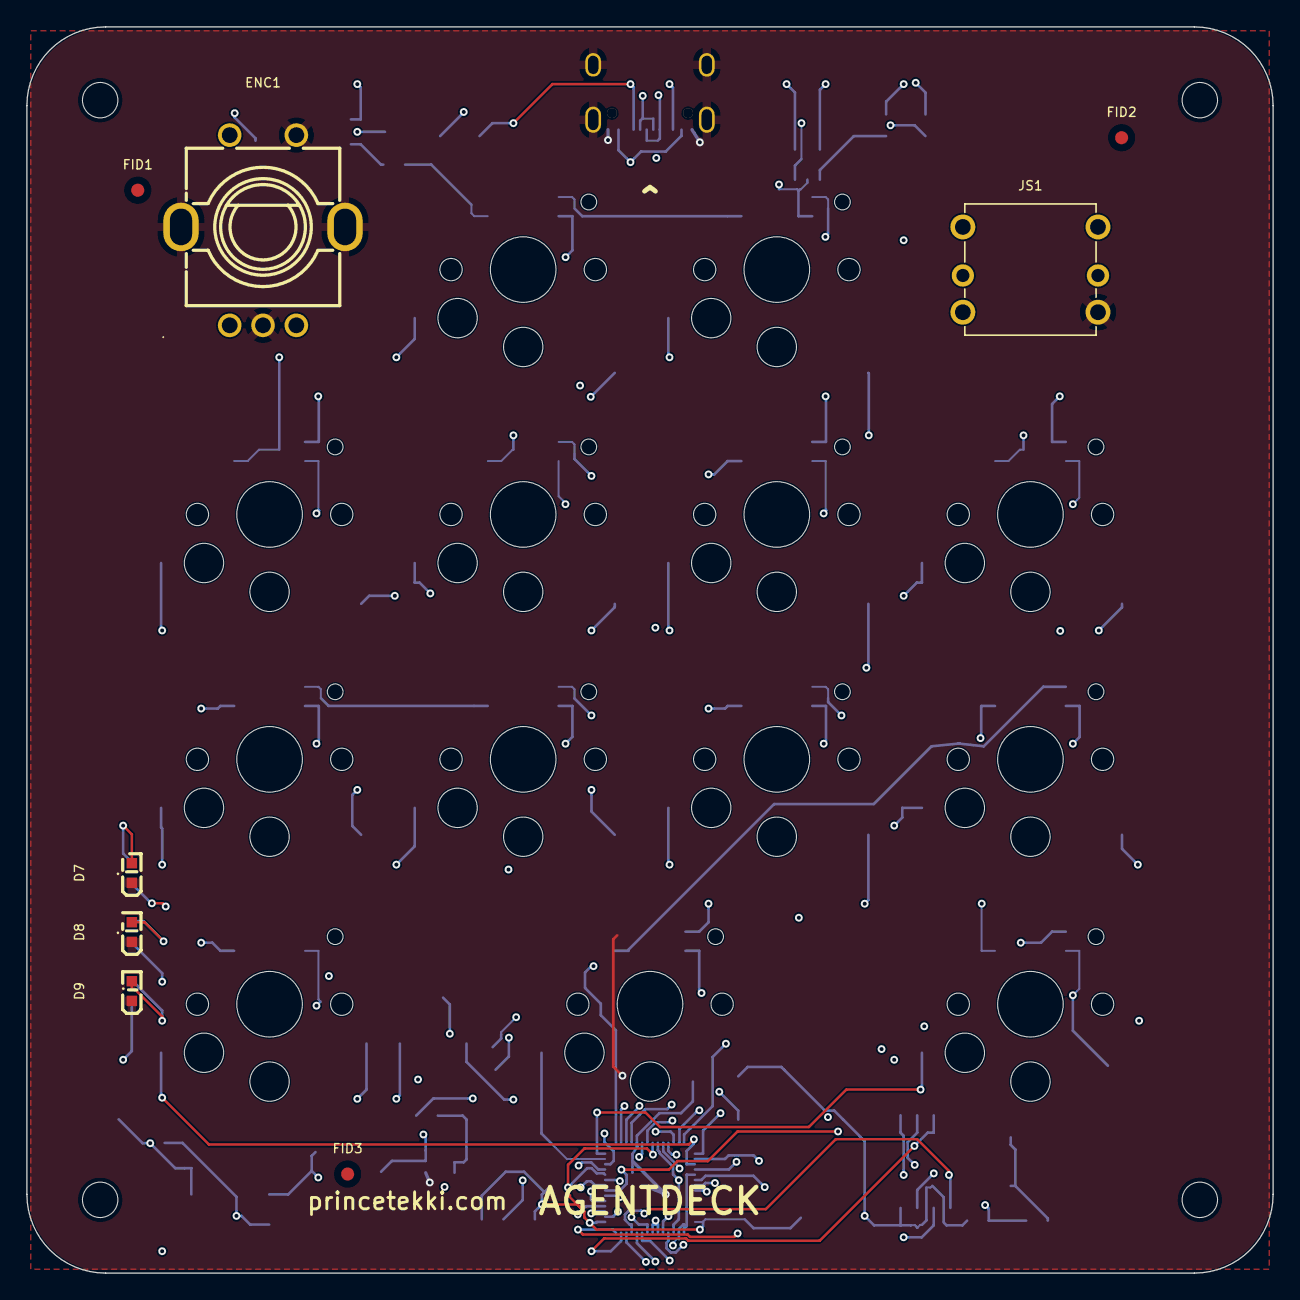
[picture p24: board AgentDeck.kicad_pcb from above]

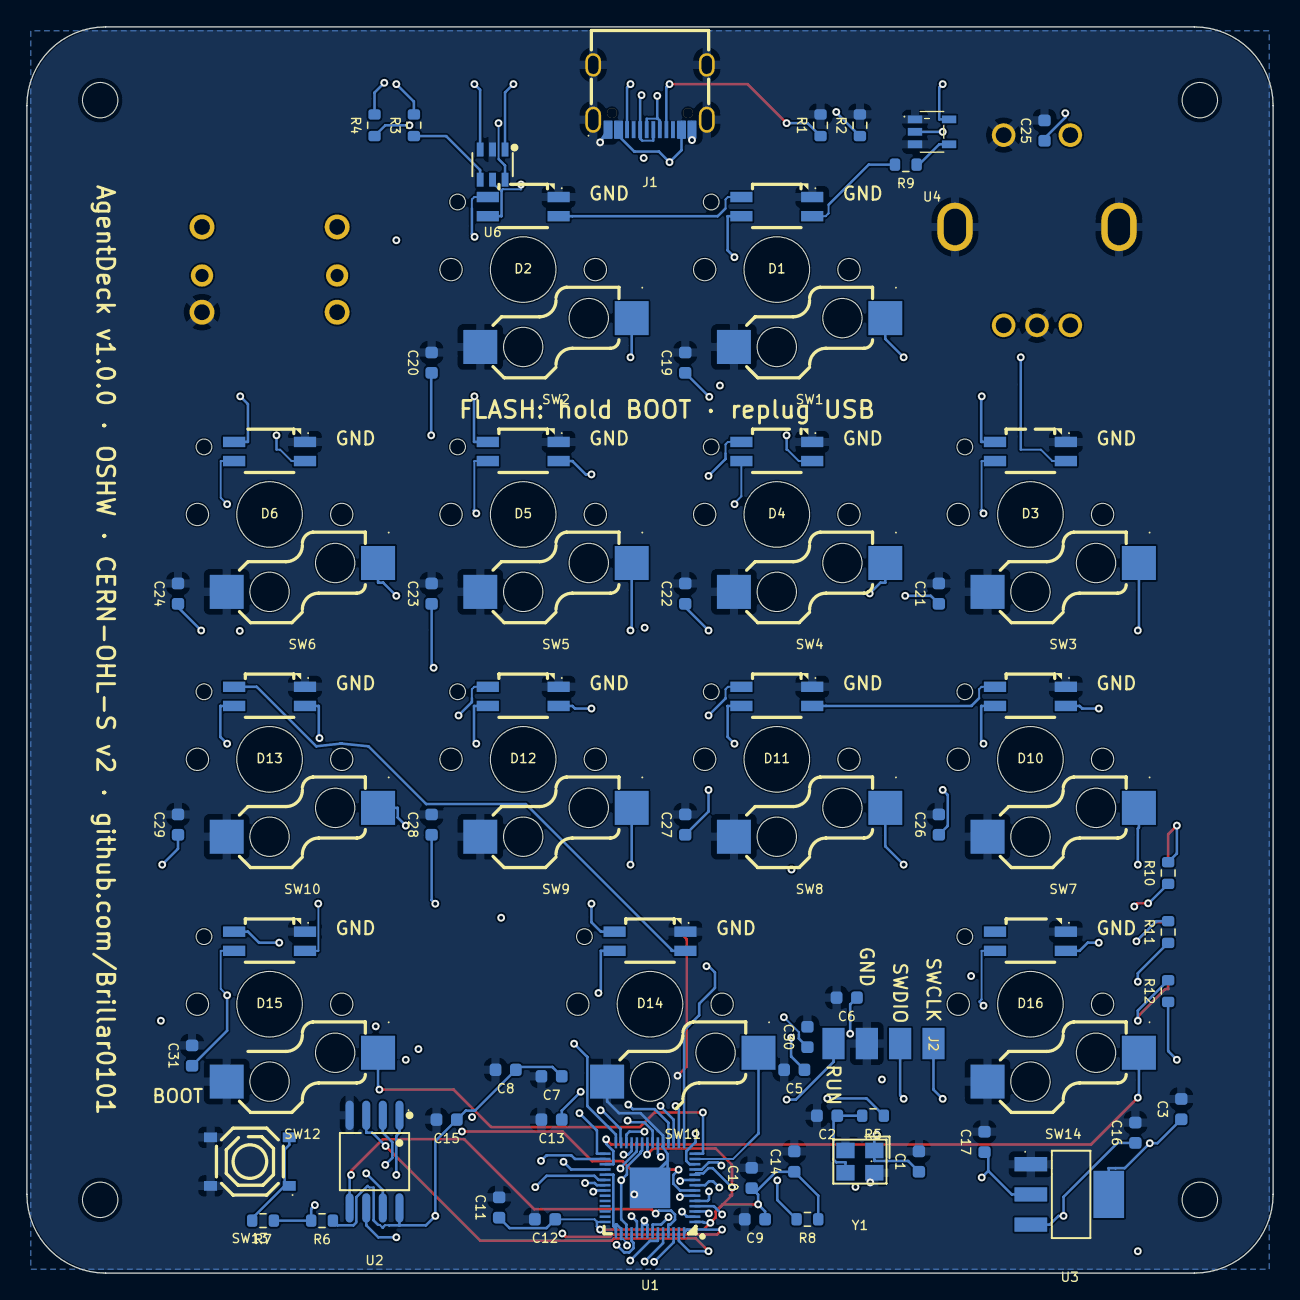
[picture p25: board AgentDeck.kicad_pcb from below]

Board: 4 copper layers, 95.0 x 95.0 mm, 101 parts (76 on the bottom side), 67 nets.

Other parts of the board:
D16: LED-SMD_4P-L3.2-W2.8-LS5.9_SK6812MINI-E
FID1, FID2, FID3: Fiducial_1mm_Mask2mm
KEY1, KEY2, KEY3, KEY4, KEY5, KEY6, KEY7, KEY8, KEY9, KEY10, KEY11, KEY12, KEY14: ChocSwitch; KeyOutline
MH1, MH2, MH3, MH4: M2.5; MountingHole_M2.5
SW14: CONN-SMD_HOTPLUGPAKAGE__C9900010116

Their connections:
GND: D16.1, SW14.2; also elsewhere on the board
LED_D13: D16.2; also elsewhere on the board
TOUCH: SW14.1; also elsewhere on the board
VBUS: D16.3; also elsewhere on the board

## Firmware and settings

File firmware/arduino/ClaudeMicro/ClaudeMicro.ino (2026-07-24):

// ClaudeMicro firmware, Arduino port (RP2040, arduino-pico core).
//
// A control surface for supervising coding agents: six agent keys that show
// each agent's live state in colour, command keys for accept / reject / new
// chat / push-to-talk, a dial for reasoning effort, and a joystick for
// navigation. This is a straight port of the CircuitPython firmware (code.py);
// behaviour, colours, key chords and the host protocol are identical.
//
// Build
// -----
//   Board:      "Raspberry Pi Pico" (or your RP2040 board), arduino-pico core
//               by Earle Philhower  (github.com/earlephilhower/arduino-pico)
//   Tools menu: USB Stack -> "Adafruit TinyUSB"   (needed for HID + Serial)
//   Libraries:  Adafruit NeoPixel
//
// Physical layout (13 keys)
// -------------------------
//     [ DIAL ]   ACCEPT   REJECT    [ JOYSTICK ]
//     AGENT1     AGENT2   AGENT3    AGENT4
//     AGENT5     AGENT6   NEWCHAT   MODEL
//     FN        [ PUSH-TO-TALK ]    MACRO
//
// Host protocol (USB serial, newline-delimited ASCII) - same as code.py
// ---------------------------------------------------------------------
//   ->  "G <slot> <state>"  agent slot 1-6:  idle|think|work|block|done|err|off
//   ->  "A <led> <state>"   raw LED index 0-12, same states
//   ->  "B <r> <g> <b>"     all LEDs one colour   ->  "X"  reset to idle
//   ->  "P"                 ping (answers "P")
//   <-  "K <name> <0|1>"    key event by role name  <-  "E <+1|-1>"  dial
//   <-  "J <U|D|L|R|C> <0|1>"  joystick

#include <Adafruit_TinyUSB.h>
#include <Adafruit_NeoPixel.h>
#include <Keyboard.h>

// ---------------------------------------------------------------- pins
static const uint8_t KEY_PINS[] = {0, 1, 2, 3, 4, 5, 6, 7, 8, 9, 10, 11, 20};
static const uint8_t NUM_KEYS   = sizeof(KEY_PINS) / sizeof(KEY_PINS[0]);  // 13
static const uint8_t ENC_A = 12, ENC_B = 13, ENC_SW = 14;
static const uint8_t JOY_PINS[] = {15, 16, 17, 18, 19};
static const uint8_t NUM_JOY    = 5;
static const char*   JOY_NAMES  = "UDLRC";   // verify on hardware; reorder if needed
static const uint8_t PIXEL_PIN  = 21;
static const uint8_t NUM_LEDS   = 13;        // one per key: 0-11 = SW1-SW12, 12 = SW14 (FN)
static const uint8_t AUX_PINS[] = {22, 23, 24};   // link, activity, error

// ---------------------------------------------------------------- roles
// key index -> role. Index 0..11 are SW1..SW12 (and LED 0..11); 12 is SW14.
enum Role {
  ACCEPT, REJECT,
  AGENT1, AGENT2, AGENT3, AGENT4, AGENT5, AGENT6,
  NEWCHAT, MODEL, PTT, MACRO, FN_ROLE
};
static const Role ROLE[NUM_KEYS] = {
  ACCEPT, REJECT,
  AGENT1, AGENT2, AGENT3, AGENT4,
  AGENT5, AGENT6, NEWCHAT, MODEL,
  PTT, MACRO, FN_ROLE
};
static const char* ROLE_NAME[NUM_KEYS] = {
  "ACCEPT", "REJECT",
  "AGENT1", "AGENT2", "AGENT3", "AGENT4",
  "AGENT5", "AGENT6", "NEWCHAT", "MODEL",
  "PTT", "MACRO", "FN"
};
static const int8_t FN_INDEX = 12;

// Ctrl+Alt combos stay clear of normal typing. The final key per role; the host
// just needs to agree. PTT is held for as long as the key is held.
static const uint8_t CK_CTRL = KEY_LEFT_CTRL, CK_ALT = KEY_LEFT_ALT, CK_SHIFT = KEY_LEFT_SHIFT;
static uint8_t roleKey(Role r) {
  switch (r) {
    case ACCEPT:  return KEY_RETURN;
    case REJECT:  return KEY_BACKSPACE;
    case AGENT1:  return '1';
    case AGENT2:  return '2';
    case AGENT3:  return '3';
    case AGENT4:  return '4';
    case AGENT5:  return '5';
    case AGENT6:  return '6';
    case NEWCHAT: return 'n';
    case MODEL:   return 'm';
    case PTT:     return ' ';
    case MACRO:   return 'x';
    default:      return 0;      // FN has no chord (it is the layer modifier)
  }
}
static const uint8_t DIAL_CW = '=', DIAL_CCW = '-', DIAL_PRESS = 't';   // effort up/down, cycle thinking
static uint8_t joyKey(char n) {
  switch (n) { case 'U': return 'i'; case 'D': return 'k';
               case 'L': return 'j'; case 'R': return 'l'; default: return 'o'; }
}

// ---------------------------------------------------------------- colours
struct RGB { uint8_t r, g, b; };
enum StateId { S_IDLE, S_THINK, S_WORK, S_BLOCK, S_DONE, S_ERR, S_OFF, S_COUNT };
static const char* STATE_NAME[S_COUNT] = {"idle", "think", "work", "block", "done", "err", "off"};
static const RGB   STATE_COLOR[S_COUNT] = {
  {3, 2, 6}, {26, 16, 0}, {30, 10, 0}, {34, 0, 0}, {0, 26, 5}, {32, 0, 14}, {0, 0, 0}
};
static RGB roleColor(Role r) {              // non-agent keys get a steady hint colour
  switch (r) {
    case ACCEPT:  return {0, 14, 3};
    case REJECT:  return {16, 0, 0};
    case NEWCHAT: return {0, 8, 14};
    case MODEL:   return {10, 0, 14};
    case PTT:     return {14, 6, 0};
    case MACRO:   return {6, 6, 6};
    case FN_ROLE: return {2, 2, 2};         // dim white at rest; lights up while the layer is held
    default:      return {0, 0, 0};
  }
}
static const RGB FLASH = {44, 44, 44};

static int8_t stateOf(const char* s) {
  for (int i = 0; i < S_COUNT; i++)
    if (strcmp(s, STATE_NAME[i]) == 0) return i;
  return -1;
}
static bool roleIsAgent(Role r) { return r >= AGENT1 && r <= AGENT6; }

// ---------------------------------------------------------------- setup
Adafruit_NeoPixel pixels(NUM_LEDS, PIXEL_PIN, NEO_GRB + NEO_KHZ800);

int8_t agentState[NUM_LEDS];                 // per-LED StateId, host driven
bool   overrideOn[NUM_LEDS];                 // raw colour from "A"/"B" active
RGB    overrideCol[NUM_LEDS];
unsigned long flashUntil[NUM_LEDS];
unsigned long lastRx = 0;
bool   fnHeld = false;

// debounce state for keys, joystick and the encoder switch
struct Btn { bool raw, stable; unsigned long t; };
Btn keyBtn[NUM_KEYS], joyBtn[NUM_JOY], encBtn;
static const unsigned long DEBOUNCE_MS = 5;

// encoder quadrature decode (divisor 4: one step per detent)
static const int8_t QDEC[16] = {0, -1, 1, 0, 1, 0, 0, -1, -1, 0, 0, 1, 0, 1, -1, 0};
uint8_t encPrev = 0;
int     encAccum = 0;

char rxbuf[64];
uint8_t rxlen = 0;

void send(const char* msg) { Serial.print(msg); Serial.print('\n'); }

// press Ctrl+Alt (+Shift on the FN layer) + a key, tap or hold
void chord(uint8_t key, bool withShift, bool hold, bool pressed) {
  if (!key) return;
  if (hold) {
    if (pressed) {
      Keyboard.press(CK_CTRL); Keyboard.press(CK_ALT);
      if (withShift) Keyboard.press(CK_SHIFT);
      Keyboard.press(key);
    } else {
      Keyboard.releaseAll();
    }
  } else if (pressed) {
    Keyboard.press(CK_CTRL); Keyboard.press(CK_ALT);
    if (withShift) Keyboard.press(CK_SHIFT);
    Keyboard.press(key);
    Keyboard.releaseAll();
  }
}
void tap(uint8_t key) { chord(key, false, false, true); }

void setup() {
  TinyUSBDevice.setManufacturerDescriptor("ClaudeMicro");
  TinyUSBDevice.setProductDescriptor("ClaudeMicro");

  for (uint8_t i = 0; i < NUM_KEYS; i++) pinMode(KEY_PINS[i], INPUT_PULLUP);
  for (uint8_t i = 0; i < NUM_JOY; i++)  pinMode(JOY_PINS[i], INPUT_PULLUP);
  pinMode(ENC_A, INPUT_PULLUP); pinMode(ENC_B, INPUT_PULLUP); pinMode(ENC_SW, INPUT_PULLUP);
  for (uint8_t i = 0; i < 3; i++) { pinMode(AUX_PINS[i], OUTPUT); digitalWrite(AUX_PINS[i], LOW); }

  for (uint8_t i = 0; i < NUM_LEDS; i++) { agentState[i] = S_IDLE; overrideOn[i] = false; flashUntil[i] = 0; }

  Keyboard.begin();
  Serial.begin(115200);
  pixels.begin();
  pixels.setBrightness(255);
  pixels.show();

  encPrev = (digitalRead(ENC_A) ? 2 : 0) | (digitalRead(ENC_B) ? 1 : 0);
}

// ---------------------------------------------------------------- render
static RGB scale(RGB c, float f) {
  auto clamp = [](int v) { return (uint8_t)(v < 0 ? 0 : v > 255 ? 255 : v); };
  return {clamp((int)(c.r * f)), clamp((int)(c.g * f)), clamp((int)(c.b * f))};
}

void render(unsigned long now) {
  float phase = fmodf((now / 1000.0f) * 2.0f, 2.0f);
  float pulse = phase < 1.0f ? phase : 2.0f - phase;
  for (uint8_t i = 0; i < NUM_LEDS; i++) {
    RGB c;
    if (now < flashUntil[i]) {
      c = FLASH;
    } else if (overrideOn[i]) {
      c = overrideCol[i];
    } else {
      Role role = ROLE[i];
      if (roleIsAgent(role)) {
        c = STATE_COLOR[agentState[i]];
        if (agentState[i] == S_THINK)      c = scale(c, 0.25f + 0.75f * pulse);
        else if (agentState[i] == S_BLOCK) c = (pulse > 0.5f) ? c : (RGB){0, 0, 0};   // blink: needs attention
      } else if (role == FN_ROLE) {
        c = fnHeld ? (RGB){30, 30, 30} : roleColor(FN_ROLE);                          // bright while layer active
      } else {
        c = roleColor(role);
        if (fnHeld) c = scale(c, 3.0f);                                               // brighten on FN layer
      }
    }
    pixels.setPixelColor(i, c.r, c.g, c.b);
  }
  pixels.show();
}

// ---------------------------------------------------------------- host RX
void handle(char* line) {
  char* p = strtok(line, " ");
  if (!p) return;
  bool ok = true;
  if (strcmp(p, "G") == 0) {                                // agent slot 1-6
    char* a = strtok(NULL, " "); char* b = strtok(NULL, " ");
    int slot = a ? atoi(a) - 1 : -1; int st = b ? stateOf(b) : -1;
    static const uint8_t AGENT_LED[6] = {2, 3, 4, 5, 6, 7};
    if (slot >= 0 && slot < 6 && st >= 0) { uint8_t led = AGENT_LED[slot]; agentState[led] = st; overrideOn[led] = false; }
    else ok = false;
  } else if (strcmp(p, "A") == 0) {                         // raw LED index
    char* a = strtok(NULL, " "); char* b = strtok(NULL, " ");
    int i = a ? atoi(a) : -1; int st = b ? stateOf(b) : -1;
    if (i >= 0 && i < NUM_LEDS && st >= 0) { agentState[i] = st; overrideOn[i] = false; }
    else ok = false;
  } else if (strcmp(p, "B") == 0) {
    char* r = strtok(NULL, " "); char* g = strtok(NULL, " "); char* b = strtok(NULL, " ");
    if (r && g && b) { RGB c = {(uint8_t)atoi(r), (uint8_t)atoi(g), (uint8_t)atoi(b)};
      for (uint8_t i = 0; i < NUM_LEDS; i++) { overrideOn[i] = true; overrideCol[i] = c; } }
    else ok = false;
  } else if (strcmp(p, "X") == 0) {
    for (uint8_t i = 0; i < NUM_LEDS; i++) { overrideOn[i] = false; agentState[i] = S_IDLE; }
  } else if (strcmp(p, "P") == 0) {
    send("P");
  }
  lastRx = millis();
  digitalWrite(AUX_PINS[1], !digitalRead(AUX_PINS[1]));
  if (!ok) digitalWrite(AUX_PINS[2], HIGH);
}

// ---------------------------------------------------------------- loop
void loop() {
  unsigned long now = millis();

  // keys
  for (uint8_t i = 0; i < NUM_KEYS; i++) {
    bool raw = (digitalRead(KEY_PINS[i]) == LOW);
    if (raw != keyBtn[i].raw) { keyBtn[i].raw = raw; keyBtn[i].t = now; }
    if (now - keyBtn[i].t > DEBOUNCE_MS && raw != keyBtn[i].stable) {
      keyBtn[i].stable = raw;
      Role role = ROLE[i];
      if (role == FN_ROLE) {
        fnHeld = raw;
      } else {
        uint8_t key = roleKey(role);
        bool hold = (role == PTT);
        chord(key, fnHeld, hold, raw);
        if (raw && i < NUM_LEDS) flashUntil[i] = now + 120;
      }
      char msg[24]; snprintf(msg, sizeof(msg), "K %s %d", ROLE_NAME[i], raw ? 1 : 0); send(msg);
    }
  }

  // joystick
  for (uint8_t i = 0; i < NUM_JOY; i++) {
    bool raw = (digitalRead(JOY_PINS[i]) == LOW);
    if (raw != joyBtn[i].raw) { joyBtn[i].raw = raw; joyBtn[i].t = now; }
    if (now - joyBtn[i].t > DEBOUNCE_MS && raw != joyBtn[i].stable) {
      joyBtn[i].stable = raw;
      char name = JOY_NAMES[i];
      if (raw) tap(joyKey(name));
      char msg[16]; snprintf(msg, sizeof(msg), "J %c %d", name, raw ? 1 : 0); send(msg);
    }
  }

  // encoder switch
  {
    bool raw = (digitalRead(ENC_SW) == LOW);
    if (raw != encBtn.raw) { encBtn.raw = raw; encBtn.t = now; }
    if (now - encBtn.t > DEBOUNCE_MS && raw != encBtn.stable) {
      encBtn.stable = raw;
      if (raw) tap(DIAL_PRESS);
    }
  }

  // encoder rotation
  uint8_t cur = (digitalRead(ENC_A) ? 2 : 0) | (digitalRead(ENC_B) ? 1 : 0);
  encAccum += QDEC[(encPrev << 2) | cur];
  encPrev = cur;
  while (encAccum >= 4)  { tap(DIAL_CW);  send("E +1"); encAccum -= 4; }
  while (encAccum <= -4) { tap(DIAL_CCW); send("E -1"); encAccum += 4; }

  // host RX
  while (Serial.available()) {
    char ch = (char)Serial.read();
    if (ch == '\n' || ch == '\r') {
      if (rxlen) { rxbuf[rxlen] = 0; handle(rxbuf); rxlen = 0; }
    } else if (rxlen < sizeof(rxbuf) - 1) {
      rxbuf[rxlen++] = ch;
    }
  }

  digitalWrite(AUX_PINS[0], (now - lastRx) < 5000 ? HIGH : LOW);   // host bridge alive
  render(now);
  delay(5);
}

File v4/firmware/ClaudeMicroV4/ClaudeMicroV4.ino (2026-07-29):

/* ClaudeMicro V4 firmware - ESP32-S3, USB HID + BLE HID, ST7789 touch LCD,
 * I2S voice (MEMS mic + NS4168 amp), wake word, touch PTT, 2x EC11.
 *
 * Build (native USB HID needs TinyUSB/OTG mode; N8R2 = 8MB flash, QSPI PSRAM):
 *   arduino-cli compile --fqbn \
 *     esp32:esp32:esp32s3:USBMode=default,CDCOnBoot=cdc,FlashSize=8M,PSRAM=enabled \
 *     v4/firmware/ClaudeMicroV4
 * Libraries: Adafruit_NeoPixel, Adafruit GFX + "Adafruit ST7735 and ST7789",
 * NimBLE-Arduino; ESP_I2S/ESP_SR come with the esp32 core (3.x).
 *
 * Host protocol (CDC, newline-delimited ASCII) = V3's plus audio + touch:
 *   inbound:  G <slot 1-6> <state> (agent-key LEDs) | A <led> <state> |
 *             B <r> <g> <b> | X | P
 *             S <line 0-3> <text>      (LCD status line, was OLED in V3)
 *             N <freq> <ms>            (NEW: notification beep via amp)
 *             R                        (NEW: reply "R <rms>" mic sanity)
 *   outbound: K <idx> <0|1> <role> | E <+-1> | T <0|1> (touch PTT) | L <layer>
 *             F <+-1> | FS <0|1>       (NEW: ENC2 rotation / switch)
 *             TK <n>                   (NEW: LCD soft-key tap, 1-4)
 *             W 1                      (NEW: wake word detected)
 * States: idle think work block done err off (V1 color language).
 */
#include <Adafruit_NeoPixel.h>
#include <Wire.h>
#include "USB.h"
#include "USBHIDKeyboard.h"
#include "pins.h"
#include "keymap.h"
#include "ble_hid.h"
#include "display.h"
#include "touch.h"
#include "audio.h"
#include "support.h"

USBHIDKeyboard usbKeyboard;
Adafruit_NeoPixel leds(NUM_LEDS, PIN_LED_DATA, NEO_GRB + NEO_KHZ800);

bool keyState[NUM_KEYS] = {};
uint32_t keyDebounce[NUM_KEYS] = {};
constexpr uint32_t DEBOUNCE_MS = 8;

extern "C" bool tud_mounted(void);   // TinyUSB: USB configured by a host
bool usbMounted() { return tud_mounted(); }

static void specialKey(const KeyBinding &b, bool pressed) {
  if (!pressed) return;
  if (strcmp(b.role, "LAYER+") == 0 && currentLayer < NUM_LAYERS - 1) currentLayer++;
  else if (strcmp(b.role, "LAYER-") == 0 && currentLayer > 0) currentLayer--;
  else return;
  Serial.printf("L %d\n", currentLayer);
  displayMarkDirty();
}

void sendKey(uint8_t keyIndex, bool pressed) {
  const KeyBinding &b = KEYMAP[currentLayer][keyIndex];
  if (b.keycode == 0) {
    specialKey(b, pressed);            // LAYER+/-, FN, PTTLOCK, host macros
  } else if (usbMounted()) {
    for (int i = 0; i < 8; i++)        // HID modifier usages 0xE0..0xE7
      if (b.mods & (1 << i)) {
        if (pressed) usbKeyboard.pressRaw(0xE0 + i);
        else usbKeyboard.releaseRaw(0xE0 + i);
      }
    if (pressed) usbKeyboard.pressRaw(b.keycode);
    else usbKeyboard.releaseRaw(b.keycode);
  } else {
    bleSendKey(b, pressed);
  }
  Serial.printf("K %d %d %s\n", keyIndex, pressed ? 1 : 0, b.role);
}

void scanMatrix() {
  for (int r = 0; r < NUM_ROWS; r++) {
    digitalWrite(ROW_PINS[r], LOW);
    delayMicroseconds(5);
    for (int c = 0; c < NUM_COLS; c++) {
      int idx = r * NUM_COLS + c;
      bool pressed = digitalRead(COL_PINS[c]) == LOW;
      if (pressed != keyState[idx] && millis() - keyDebounce[idx] > DEBOUNCE_MS) {
        keyState[idx] = pressed;
        keyDebounce[idx] = millis();
        sendKey(idx, pressed);
      }
    }
    digitalWrite(ROW_PINS[r], HIGH);
  }
}

void setup() {
  for (int r = 0; r < NUM_ROWS; r++) { pinMode(ROW_PINS[r], OUTPUT); digitalWrite(ROW_PINS[r], HIGH); }
  for (int c = 0; c < NUM_COLS; c++) pinMode(COL_PINS[c], INPUT_PULLUP);
  pinMode(PIN_ENC_A, INPUT_PULLUP); pinMode(PIN_ENC_B, INPUT_PULLUP);
  pinMode(PIN_ENC_SW, INPUT_PULLUP);
  pinMode(PIN_ENC2_A, INPUT_PULLUP); pinMode(PIN_ENC2_B, INPUT_PULLUP);
  pinMode(PIN_ENC2_SW, INPUT_PULLUP);

  leds.begin(); leds.setBrightness(60); leds.show();
  Wire.begin(PIN_I2C_SDA, PIN_I2C_SCL);
  USB.productName("ClaudeMicroV4");    // claude_bridge.py matches "ClaudeMicro"
  USB.manufacturerName("princetekki");
  usbKeyboard.begin(); USB.begin();
  bleBegin("ClaudeMicroV4");
  Serial.begin(115200);
  displayBegin();
  touchPanelBegin();
  audioBegin();
  displaySplash();
}

void loop() {
  scanMatrix();
  pollEncoder();
  pollEncoder2();
  pollTouch();        // native touchRead(PIN_TOUCH) vs calibrated threshold -> PTT
  touchPanelPoll();   // CST816 polled @30 Hz -> TK soft-key events
  pollHostSerial();   // G/A/B/X/P/S/N/R commands -> LED + LCD + audio
  audioPoll();        // deferred wake-word event -> W 1 + LED flash
  displayTick();      // battery %, layer, agent states, BLE/USB indicator
}

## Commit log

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2026-07-24 Move LEDs under keys
    [ClaudeMicro.kicad_pcb]
2026-07-24 Add changelog, silk license
    [ClaudeMicro.kicad_pcb]
2026-07-24 Move project to hardware
    [.backups_before_hwreorg.kicad_pcb, .backups_before_ledmove.kicad_pcb, ClaudeMicro.kicad_pcb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]
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2026-07-28 fix: clear DRC errors, adjust silkscreen, regenerate fab package
    - Add GND stitching via at (55.605, 88.624) connecting orphan B.Cu
    island carrying C12 pad 2 (decoupling cap ground was floating)
    - Remove 9 redundant vias drilled on top of ENC1/JS1/J1 PTH pad holes
    - Convert 26 zero-annular-ring switch alignment posts (SW1-SW14) to NPTH
    - Silkscreen text repositioned; clears silk_edge_clearance warning
    - Schematic resaved by KiCad 10 (format normalization, sch_revision V0.1)
    - Regenerate gerbers, drills, CPL from DRC-clean board (0 errors)
    [ClaudeMicro-B_Cu.gbl, ClaudeMicro-B_Mask.gbs, ClaudeMicro-B_Paste.gbp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]
2026-07-28 perf: upsize all via drills to 0.3mm minimum for standard fab pricing
    175x 0.3/0.15 and 92x 0.2-drill vias upsized to 0.3mm drill; 7 vias
    nudged 0.06mm clear of adjacent tracks. DRC: 0 errors, 0 unconnected.
    Drops JLCPCB high-precision surcharges (~$55/batch).
    [ClaudeMicro-B_Cu.gbl, ClaudeMicro-B_Mask.gbs, ClaudeMicro-B_Paste.gbp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]
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2026-07-29 feat(v3): script-generated schematic, ERC clean - 136 components, 102 nets
    - v3/tools/gen_schematic.py: emitter ported from NeuralCard, prints GPIO map
    - v3/hardware/: ClaudeMicroV3.kicad_sch (ERC 0 errors), V3.kicad_sym,
    lib tables, project file, netlist
    - Load-share power path per NeuralCard pattern + SS34 diode-OR leg;
    AHCT buffer on VSYS_SW; LED rail behind power switch, charging always live
    - firmware pins.h synced to generator PINOUT; recompiles clean (53% flash)
    [ClaudeMicroV3.kicad_sch]
2026-07-29 feat(v3): PCB placed and routed - 150x110 2-layer, DRC clean
    - 142 footprints, 102 nets, 786 tracks, 328 vias (all 0.6/0.3 - standard fab)
    - Datasheet-rule placement: antenna overhang+keepout, touch-pad copper void,
    battery pocket keepout, LEDs reverse-mount under keys, TP4056 thermal pour
    - New footprints: ChocV1_Direct (PG1350 3.4mm stem), ESOP-8 TP4056,
    OLED land, MSK12C02; freerouting pipeline ported (place/export_dsn/finish_v3)
    - verify_parts.py: fab/courtyard/bbox dim matching; PARTS.yaml dims trued
    - Documented deviations: USB pair unmatched (fine at full-speed, V1 precedent),
    J1-local 0.05mm dru relaxation inside connector footprint only
    [ClaudeMicroV3.kicad_pcb]
2026-07-29 feat(v3): parameterized enclosure + full 3D assembly
    - make_case_v3.py / build_assembly_v3.py / export_positions_v3.py: all dims
    read live from the PCB + PARTS.yaml heights (no hardcoded literals)
    - Case 155x115x16.4: battery pocket, OLED flush-glass ledge, 1mm touch skin
    with finger-guide ring, antenna slot (module overhangs 6.5mm), V1 fastener
    system; all STLs manifold; height table: 20/20 PASS
    - ClaudeMicroV3-assembled.blend: 311 objects, board+switches+caps+knob+battery
    [ClaudeMicroV3-assembled.blend, case-bottom.stl, case-cover-plug.stl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]
2026-07-29 feat(v3): fab package + gated LCSC order list; firmware protocol polish
    - v3/fab/: 2-layer gerbers + drills (min drill 0.30mm), ClaudeMicroV3-gerbers.zip
    - v3/tools/order_list.py: LCSC cart CSV from PARTS.yaml with spares policy;
    refuses to emit final order while any line is stock-VERIFY (7 remain)
    - firmware: real tud_mounted(), HID modifier handling, layer keys, richer
    K/L protocol messages; still 53% flash
    [ClaudeMicroV3-B_Cu.gbl, ClaudeMicroV3-B_Mask.gbs, ClaudeMicroV3-B_Paste.gbp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]
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2026-07-29 fix(v3): live LCSC stock verification - 6/7 confirmed, JST part number corrected
    - C265088 was B6B-PH-SM4 (6-pin vertical, wrong part) -> C295747
    S2B-PH-SM4-TB 2-pin right-angle; footprint/schematic were already correct
    - TP4056 confirmed as ESOP-8 variant matching our footprint
    - All lines CONFIRMED with live qty/prices except OLED C5248080 (2 pcs left)
    [order-list.csv]
2026-07-29 fix(v3): resolve OLED sourcing - generic 4-pin I2C breakout, gate open
    LCSC's 0.96" class is bare 30-pin FPC COG glass (verified against the
    C18723026 datasheet pin table + C5248080's 2-pc remnant) - incompatible
    with the 4-pad land and needing external charge-pump passives. The V3
    footprint was designed for the ubiquitous 4-pin GND/VCC/SCL/SDA breakout;
    OLED moves to EXTERNAL sourcing alongside switches and battery.
    order_list.py now exits 0: LCSC subtotal $46.92/3 boards + 3 external lines.
    [order-list.csv]
2026-07-29 chore(v3): blend resave from interactive Blender session
    [ClaudeMicroV3-assembled.blend]
2026-07-29 feat(v3): assembly dressing - modeled fasteners, PBR materials, preview render
    - dress_assembly.py: 6x M2.5x8 ISO 7046 countersunk screws + 6x brass
    heat-set inserts as real geometry; material set (ABS case, steel, brass,
    glossy caps, knurled knob)
    - ClaudeMicroV3-preview.png: closed-assembly EEVEE render
    - .gitignore: anchor V1 tools/ pattern to root - it was silently swallowing
    new files under v3/tools/
    [ClaudeMicroV3-assembled.blend]
2026-07-29 fix(v3): track the entire v3 toolchain - was silently gitignored
    gen_schematic, place_pcb, export_dsn, finish_v3, verify_parts, order_list,
    export_positions_v3, make_case_v3, build_assembly_v3: all nine pipeline
    scripts existed only on disk - the unanchored 'tools/' ignore pattern made
    every earlier 'git add v3/' skip them without warning. The reproducibility
    promise of DESIGN-V3 (rule 5) is now actually true.
    [gen_schematic.py, order_list.py, place_pcb.py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]
2026-07-29 revert: unauthorized V4 scaffold (767ac80)
    Pushed by a runaway background agent without a request. V4 remains an
    open decision; the scaffold stays recoverable in history if wanted.
    [PARTS.yaml]
2026-07-29 V4 phase 1: ERC-clean generated schematic - 142 components, 106 nets, audio + touch LCD
    [ClaudeMicroV4.kicad_sch]
2026-07-30 V4 wake word fits: custom 8MB partition table, ESP-SR linked, include-guard bug fixed
    [partitions.csv]
2026-08-11 route v4 board
    Phase 2 complete: the V4 board is fully routed and DRC-clean (0 errors,
    0 unconnected, 970 tracks, 380 vias).
    freerouting closed 167/172 connections and stalled at pass 8; finish_v4
    imported the SES, poured GND and VSYS_SW, and bridged 30 pour clusters.
    knit_maze's A* recovered VSYS_SW C6.1. Three defects were left over and
    are fixed here:
    - USB_DP short. phase 4b0's add_seg() wrote tracks with no clearance
    guard - the only unguarded path in that block - driving the B6 descent
    straight through the VBAT_SNS run. add_seg now builds the model lazily
    (so it sees the del_box rip-ups above it) and checks seg_clear before
    committing, like the BESPOKE block. Without this the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
    [ClaudeMicroV4.kicad_pcb, ClaudeMicroV4.kicad_sch]
2026-08-11 clean v1 silkscreen
    First silk pass on V1: 107 warnings down to 17, all remaining ones
    pre-existing and unrelated to silk.
    silk_over_copper 79 -> 0
    silk_overlap 7 -> 0
    text_height 4 -> 0
    silk_pass clips every silk graphic 0.15 mm clear of same-side pads and
    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
    [ClaudeMicro.kicad_pcb]
2026-08-11 rename to agentdeck 1.0.0
    The product is renamed from ClaudeMicro to AgentDeck for 1.0.0. "Claude" is
    Anthropic's trademark and this ships as OSHWA-marked open hardware with the
    name on the silk; "Micro" also stopped describing a 150x110 mm V4 deck. Note
    AgentDeck collides with an existing project (github.com/puritysb/AgentDeck) -
    chosen anyway.
    Renamed across board, schematic, netlist, libraries, firmware, host bridge and
    docs. Silk reads AGENTDECK and AgentDeck v1.0.0. Generated gerbers under
    fab/gerbers are left alone: they are the artifact of the released v0.1.0 and
    should be regenerated rather than string-edited.
    Also in this commit, all verified 0 errors / 0 unconnected:
    - silkscree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
    [AgentDeck-BOM-v1.0.0.csv, AgentDeck-bom.csv, AgentDeck-v2-assembled.blend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]
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2026-08-11 grow board to 95mm
    Board 95.1x95.1 (was 90x90): outline +2.5mm/side, corner arcs r6 preserved.
    MH1-4 moved to (3.086,3.086)+mirrors, M2.5 confirmed (BOM corrected from M2).
    J1 USB-C moved to y=2.87, face 0.15mm inside the new edge. U1 down 2mm to (45,86).
    All pours expanded to -2.20..92.20. Full reroute with freerouting 2.3.0
    (2.2.4 hangs; 2.3.0 fixes it - #739). DRC: 0 errors, 42 warnings.
    KNOWN OPEN (2 ratsnest lines, fix by hand in pcbnew):
    - U1 pin 19 (TESTEN->GND): dogleg laid at (44.0,82.57)->(43.66,84.85) into EP
    but the pad does not register touching tracks; verify/redraw in GUI.
    - U1 pin 10 (IOVDD): unrouted; via-blocked cage (K1/K5 In1, K8/K9 B.Cu,
    K6 diag). +3V3 F.Cu brid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
    [AgentDeck-BOM-v1.0.0.csv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]
2026-08-11 stitch gnd add pour hookup
    Pour-aware EP stitch via chain (pad19->dogleg->EP->via->In1 pour, all links
    verified by the connectivity API) plus a direct B.Cu run into verified pour
    copper. kicad-cli still reports the pad19 ratsnest line (its refill may
    differ from the saved fill - verify in pcbnew GUI, likely phantom).
    Pad 10 (+3V3) remains genuinely unrouted: via-caged on all four layers;
    the F.Cu +3V3 bridge passes over the pad at x~41.4 as the GUI hookup point.
    DRC: 0 errors, 42 warnings, 2 unconnected items.
    [AgentDeck.kicad_pcb]
2026-08-11 route cage nets
    Freerouting 2.3.0 with the pocket cage (K1/K5/K6/K8/K9/K10) ripped and GND
    pinned through U1-19/57 + C12 solved the two 'impossible' connections:
    pad 10 (+3V3) is now routed and the GND cluster join was built by the router.
    Subsequent iterations landed K5/K8/K9/K10 but rip up the GND join when
    re-routing (imported wiring is not fixed), oscillating at 3 unconnected.
    Current best adopted state: 0 DRC errors, 3 unconnected (U1-19 GND join,
    K1 SW1->U1, K6 SW6->U1). These three want interactive routing.
    [AgentDeck.kicad_pcb]
2026-08-11 restore best routed state
    The cage-net campaign (K1 via donor transplant etc.) net-regressed from 2 to
    5 unconnected - each win evicted an equal loss; the pocket is at capacity in
    that era's layout. e5d29c3's board is the best known: 0 errors, 2 unconnected
    (pin-19 GND join, pad-10 +3V3). Kept cage-era wiring as a donor in scratch.
    [AgentDeck.kicad_pcb]
2026-08-11 restore copper zones
    Deleted then re-added the 5 pours (user request). User's GUI routing between
    delete and restore closed the pin-19 GND and pad-10 +3V3 connections that
    scripts could not. With pours refilled: 0 DRC errors, 1 unconnected (K7 -
    an In1 switch escape needs 1 via up to the B.Cu net, blocked by the +3V3
    wall + K4/K9/AUX3 congestion; a push-shove GUI job).
    [AgentDeck.kicad_pcb]
2026-08-11 complete v1 routing
    Board fully routed: 0 DRC errors, 0 unconnected, 92 nets complete on 95x95mm.
    Final K7 escape routed in pcbnew (push-shove); zones refilled to clear the
    stale-fill overlaps. Gerbers + drill regenerated for the finished board.
    Remaining 42 warnings are non-blocking: JLC footprint-lib notes (17),
    pour islands / isolated copper (15, cosmetic), courtyard overlaps (3),
    annular/padstack/thermal (pre-existing class). Manufacturable state.
    [AgentDeck-B_Cu.gbl, AgentDeck-B_Mask.gbs, AgentDeck-B_Paste.gbp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]
2026-08-11 fix erc errors
    U6 (USBLC6-2SC6 ESD diode) pins 1 and 3 were type 'input', triggering
    'input pin not driven' - false positive for a passive protection clamp on
    the USB data lines. Changed to 'passive' (correct electrical type for a
    TVS/ESD I/O tap). ERC errors 2 -> 0. Netlist and board unaffected (pin
    electrical type is schematic metadata only). 124 pin_to_pin warnings remain
    (easyeda-import 'Unspecified' pin types, cosmetic).
    [AgentDeck.kicad_sch]
2026-08-11 regenerate case for routed board
    Fresh case from enclosure/src/generate_case.py, verified against the final
    95x95 routed PCB:
    - board fits tray pocket with 0.20 mm/side clearance
    - 4 screws exactly coaxial with PCB MH holes (3.086,3.086)+mirrors
    - M2.5x8 button-head -> 2.9 lid hole -> 2.7 PCB hole -> 3.6 insert bore,
    full 5 mm heat-set engagement, no bottoming
    - USB slot covers J1, 2.55 mm case overhang all round
    3 watertight STLs (lid/tray/cover), 0 non-manifold edges.
    [case-bottom.stl, case-cover-plug.stl, case-top-lid.stl]
2026-08-11 add fasteners to bom
    Itemize the case fastener stack (was one wrong 'standoff + screw' line):
    - 4x M2.5 x 8 button-head screw (ISO 7380) - corrected from socket cap
    - 4x M2.5 heat-set insert 4.0mm OD x 5.0mm - the threaded 'nut', was missing
    - 4x printed cover cap (case-cover-plug.stl)
    Matches the fit-verified generated case.
    [AgentDeck-BOM-v1.0.0.csv]
2026-08-11 loosen case fit
    FIT 0.25 -> 0.40 mm/side for easy FDM drop-in. Pocket now 95.80mm vs 95.10
    board = 0.35mm clearance per side. Screws, connectors, key cutouts unchanged.
    [case-bottom.stl, case-cover-plug.stl, case-top-lid.stl]
2026-08-11 remake both case parts
    Regenerated top lid and bottom tray from enclosure/src/generate_case.py:
    - lid: 13 key cutouts, encoder, joystick, USB-C notch (14mm + 18mm flare) over
    J1, 3 LED windows, BOOTSEL pinhole, 4 M2.5 counterbores
    - tray: board pocket (0.35mm loose fit), 4 bosses topping at PCB underside,
    3.6mm heat-set insert bores, USB pass-through
    Both watertight (0 non-manifold edges). Fit-verified vs the routed 95x95 PCB.
    Blender assembly refreshed with both parts.
    [case-bottom.stl, case-cover-plug.stl, case-top-lid.stl]
2026-08-11 tighten usb opening
    Lid USB cut was a 14 x 9mm trench through the top face - read as a gap, not
    a port. Now hugs the connector: 10.5mm wide (shell 8.94 + 0.78/side), trench
    ends 6.5mm (body 6.04). 18mm flared mouth unchanged - overmould stays outside
    the wall. Plug entry and seating re-verified.
    [case-bottom.stl, case-cover-plug.stl, case-top-lid.stl]
2026-08-11 fix stale cover caps
    The assembly still had 8 stale CoverPlug/BoreCap objects from the ORIGINAL
    case at the ORIGINAL screw positions - 4mm off the current counterbores and
    undersized (user's screenshot: empty bore + offset yellow disc). Removed all;
    seated 4 instances of the current case-cover-plug.stl (5.0mm) in the
    counterbores at (3.086,3.086)+mirrors, flush with the lid top.
    Shaft holes verified present in the lid STL at all 4 corners.
2026-08-11 solid top side usb port
    Replaced the open USB trench with a side-port design (user request):
    - underside pocket over J1's 3.2mm shell, 0.55mm solid roof - top face
    unbroken over the connector and board
    - side tunnel through the front wall for the plug shell (10.5 x 3.4mm)
    - slim full-height rim notch (12.8 x 2.35mm) so the 6.5mm-tall overmould
    (taller than the case, can never enter) seats the plug fully (6mm insertion)
    Verified by triangle-coverage: roof SOLID over connector, notch open, rim
    solid elsewhere. Both shells watertight.
    [case-bottom.stl, case-cover-plug.stl, case-top-lid.stl]
2026-08-11 usb port to tray wall
    User correction: J1 hangs BELOW the board (all SMD parts face down into the
    tray; only switches/knobs come up through the lid). USB port moved from the
    lid to the tray front wall: shell tunnel 10.5mm wide x z -3.5..0.3, inside a
    12.8mm rim recess for the cable overmould (centred z=-1.6). Lid front edge
    now completely solid - verified by triangle coverage at rim, connector body,
    and outer edge.
    [case-bottom.stl, case-cover-plug.stl, case-top-lid.stl]
2026-08-11 minimize usb opening
    Tray USB opening shrunk to plug-only size: tunnel 9.6 x 3.6mm (shell 8.94 x
    3.26 + 0.33/side), overmould recess height-limited to 6.7mm (was full 8mm
    tray height) and narrowed to 12.6mm. Wall material retained below the recess.
    [case-bottom.stl, case-cover-plug.stl, case-top-lid.stl]
2026-08-11 shrink usb recess further
    Collar recess 12.6x6.7 -> 11.4x5.4 (slim overmould 10.5x5 + margin), tunnel
    unchanged at 9.6x3.6. This is the functional minimum: chunky cable overmoulds
    will not seat - the usbnotch box is the dimension to widen if needed.
    [case-bottom.stl, case-cover-plug.stl, case-top-lid.stl]
2026-08-11 soften case edges
    0.6mm bevel (3 segments) on every edge sharper than 40deg across all three
    parts - outer corners, key cutout rims, USB port mouth. Face counts up ~8x
    (6537/4678/338), still watertight 0 non-manifold.
    [case-bottom.stl, case-cover-plug.stl, case-top-lid.stl]
2026-08-11 fix assembly board model
    The assembly carried TWO board models - the current one plus a stale 90mm
    board whose holes sat at the old corner positions. That stale twin was the
    visible 'misaligned holes / case too big'. All 245 old objects purged; the
    final routed 95mm board imported once and seated. All 4 screw axes verified
    passing through the board holes.
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2026-08-11 open usb port simplify caps
    USB port: the 0.6mm edge bevel ran after the cuts and choked the 3.6mm
    opening to ~2.4mm effective (below the 3.26mm plug shell) - the 'something
    covering the usb-c'. Port now cut post-bevel; 9/9 probe rays pass clear.
    Keycaps: all text legends removed (no FN/PTT/MACRO words); icons simplified
    to the plainest Lucide glyphs - check, x, plus, bot, mic, zap, layers; dice
    1-6 unchanged on the agent keys.
    [case-bottom.stl, case-top-lid.stl]
2026-08-11 shrink keycap icons
    All 13 icon decals scaled to 68%, re-centred on their caps.
    [AgentDeck-v2-assembled.blend]
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2026-08-11 fix v2 ref ranges
    [PARTS.yaml]
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2026-08-12 flip sockets add fab
    [AgentDeckV2-BOM.csv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]
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2026-08-31 remove unbuilt v2-v4
    Refocus on manufacturing and validating V1 before designing any
    successor. V2-V4 existed only as paper designs; git history keeps them.
    Claude-Session: https://claude.ai/code/session_01GWeFSftAaDQLi7MhELLoa4
    [AgentDeckV2-BOM.csv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]
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2026-09-01 add v2 wireless design
    20-key 4x5 ESP32-S3 board cut from the recovered V3 platform: joystick
    in, touch pad out, 103450 battery pocket, 2-layer. Schematic ERC clean;
    PCB placed, autorouted and finished by v2/tools with USB pair and
    decoupling comb pre-routed. 0 DRC errors; 7 links and 2 pour islands
    left for hand routing (see CHANGELOG). Firmware re-cut for 20 keys and
    compiles.
    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
    [AgentDeckV2.kicad_pcb, AgentDeckV2.kicad_sch]
2026-09-01 strip v2 routing
    Placement-only board for hand routing: all tracks, vias and copper pours
    removed (799 tracks, 306 vias, 3 zones). The autorouted version stays in
    history at f1eb7db. Keepouts, outline, holes and silk untouched.
    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
    [AgentDeckV2.kicad_pcb]
2026-09-01 source v2 from jlcpcb
    Every LCSC code re-checked against the JLCPCB assembly library; LCSC
    field on all symbols; JLCPCB BOM/CPL/consigned list in v2/fab. LDO ->
    RT9080-33GJ5 (ME6211 had 17 in stock), joystick -> SKRHABE010 SMD with
    the JLC library footprint. STEP models pulled per LCSC code.
    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
    [AgentDeckV2.kicad_sch, consigned-parts.csv, jlcpcb-bom.csv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]
2026-09-01 oled from jlcpcb library
    C5248080 module with JLC footprint and STEP replaces the stand-in and the
    generated model; OLED joins the JLCPCB BOM.
    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
    [AgentDeckV2.kicad_sch, consigned-parts.csv, jlcpcb-bom.csv]
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

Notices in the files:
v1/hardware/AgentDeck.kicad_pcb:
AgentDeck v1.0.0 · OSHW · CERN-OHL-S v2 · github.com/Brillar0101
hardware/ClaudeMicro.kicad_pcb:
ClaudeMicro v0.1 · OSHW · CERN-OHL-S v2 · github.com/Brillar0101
